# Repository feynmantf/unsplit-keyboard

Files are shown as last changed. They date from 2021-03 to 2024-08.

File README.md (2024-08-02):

# this project has been archived and abandoned in pursuit of hall-effect
# ~~WIP!! (firmware and schematic work but i havent gotten around to the new pcb layout) - I will get back to working on it when the semester ends/when I have the time~~
## all files in [early revisions/final but with microcontrollers](/early%20revisions/final%20but%20with%20microcontrollers) still work and can be manufactured (see [BOM](/early%20revisions/final%20but%20with%20microcontrollers/bom%20and%20cpl%20files) and [Gerber](/early%20revisions/final%20but%20with%20microcontrollers/gerber%20and%20drill%20files) folders), i just dont like the layout lol
## i plan on coming back to this project sometime before the end of 2024, but i cant promise it will look the same

# kaluza kb
kaluza kb pcb, layout, and case files (plus other useful stuff like firmware/images)
(documentation in progress)

## design logic
i wanted a keyboard that was both 65% and had extra function keys. i also wanted an oled panel and rotary encoder. and, as an added bonus, i love seeing through hole components on a keyboard. therefore, all of these features have been included

## sample images (they exist for the old revisions if you want to dig through the file tree)

### case images/renders:

### pcb images/renders:
#### pcb front (old version):
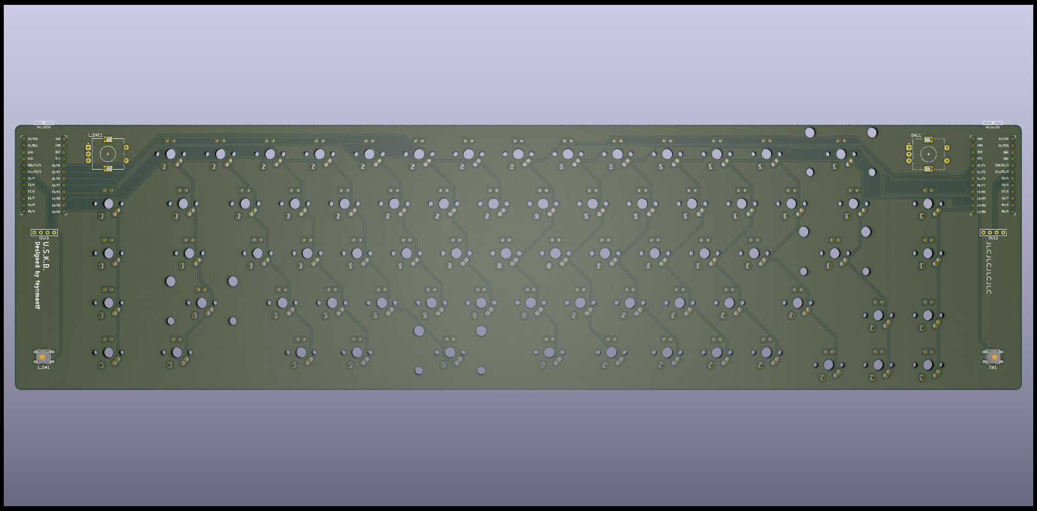
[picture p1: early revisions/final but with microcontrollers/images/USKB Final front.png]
pcb front

#### pcb back (old version):
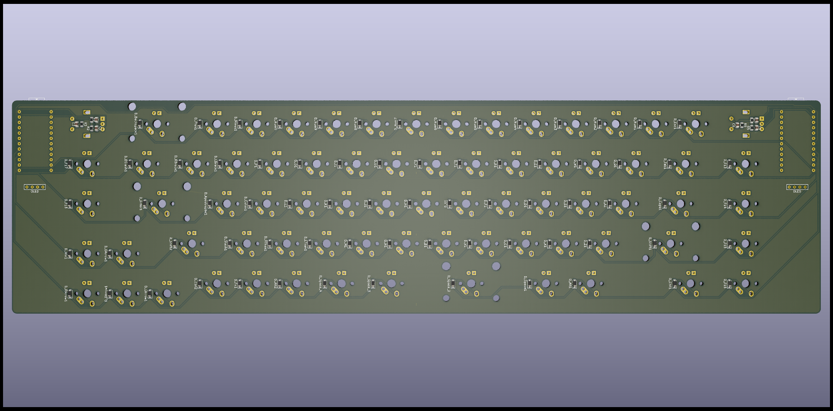
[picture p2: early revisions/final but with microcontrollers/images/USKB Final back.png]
pcb back

### schematic (new version):
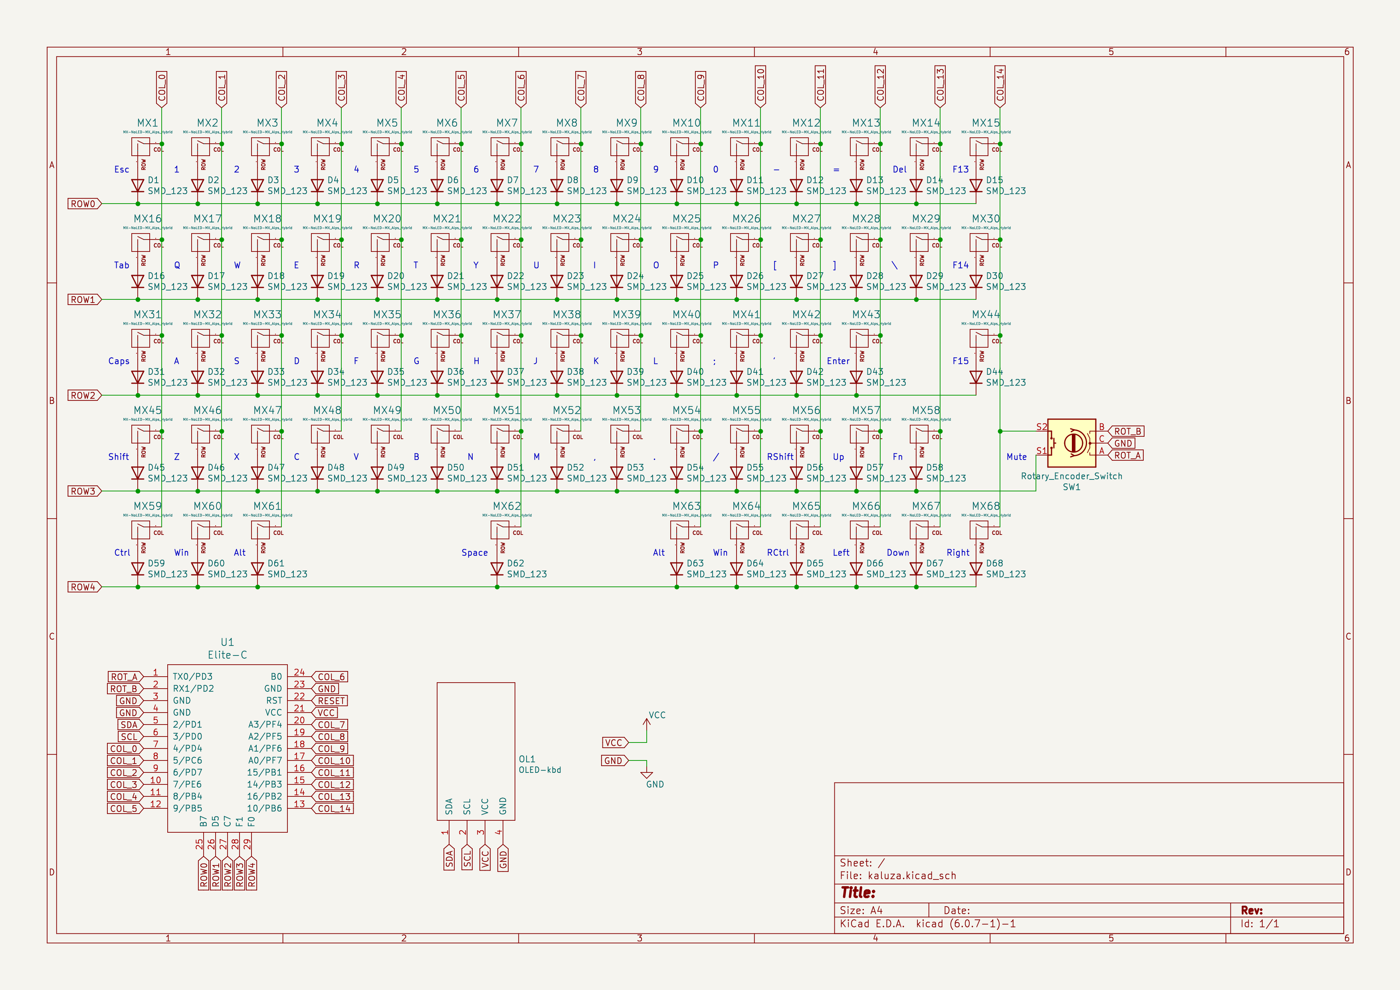
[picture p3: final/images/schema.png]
schematic


### handwired circuit test images:
handwired front
handwired back
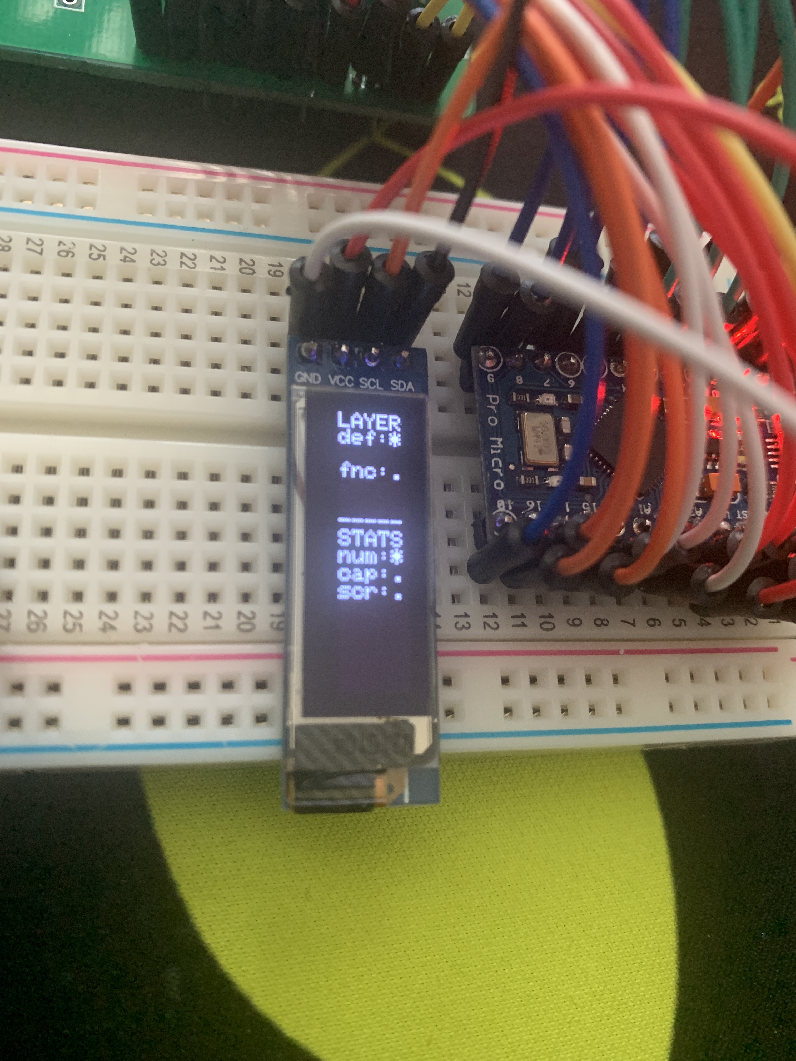
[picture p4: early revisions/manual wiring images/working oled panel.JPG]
oled panel test


## parts needed to build the board (not included in these files)
### parts you must source
- keyswitches (x80)
- keycaps (base kit and spacebar)
- pcb stabilizers (2u x4 and 6.25u x1)
- rotary knob (x1)
- rotary encoder (ec11 with switch) (x1)
- oled (0.91 inch, SSD1306) (x1)
- switch diodes (x80)
- elite-c v4 (x1)

### parts to get manufactured
- pcb
- plate (carbon fiber or sheet metal) (2mm)
- case (3d printed)
- leaf springs (carbon fiber) (1mm)

## basic instructions
- buy all the parts listed above
- get the pcb printed (from jlcpcb or some other service)
- get the plate, case, and leaf springs printed
- flash firmware and test the board to make sure everything works
- screw stabilizers into pcb
- align and place plate on top of pcb
- clip switches into place and slot them into the pcb
- solder switches to the pcb (locations marked on pcb)
- solder rotary encoder onto pcb (locations marked on pcb)
- solder oled panel onto pcb (locations marked on pcb)
- test everything again
- screw leaf springs into pcb (locations marked on pcb)
- put assembled pcb and plate in the case, and screw the case together
- you should be done now !!

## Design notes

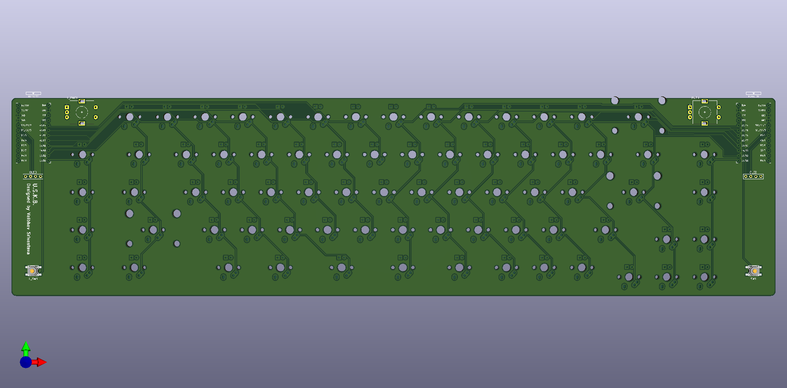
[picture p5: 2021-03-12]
early revisions/not really final cuz its missing one wire which means i need to redo the schematic lolololol/images/USKB Final but wrong and needs to be redone sadge (front).png

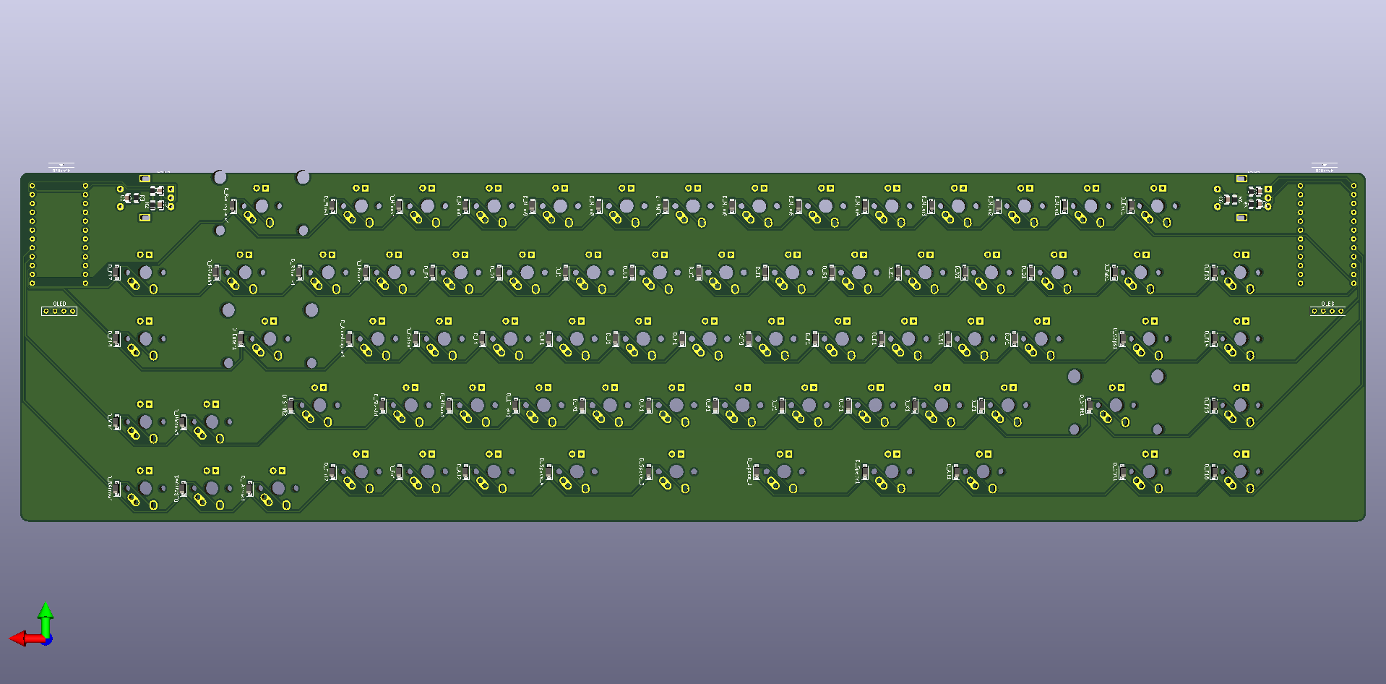
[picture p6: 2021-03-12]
early revisions/not really final cuz its missing one wire which means i need to redo the schematic lolololol/images/USKB Final but wrong and needs to be redone sadge (back).png

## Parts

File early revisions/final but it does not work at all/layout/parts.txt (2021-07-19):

keyswitches (x69)
keycaps (base kit and spacebar in 6.25u)
pcb or plate mount stabilizers (2u x3 and 1c 6.25u)
switch diodes (x70) (specs in BOM and surface mounted on pcb by manufacturer)
capacitors (x11) (specs in BOM and surface mounted on pcb by manufacturer)
resistors (x9) (specs in BOM and surface mounted on pcb by manufacturer)
reset switch (x1) (specs in BOM and surface mounted on pcb by manufacturer)
xtal crystal (x1) (specs in BOM and surface mounted on pcb by manufacturer)
usb-c port (x1) (specs in BOM and surface mounted on pcb by manufacturer)
rotary knob (x1)
rotary encoder (ec11 with switch) (x1)
oled (0.91 inch, SSD1306) (x1)

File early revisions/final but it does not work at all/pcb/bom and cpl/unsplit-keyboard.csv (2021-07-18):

Comment | Designator | Footprint | LCSC
22p | C1,C2 | Capacitor_SMD:C_0805_2012Metric | C1804
1u | C11 | Capacitor_SMD:C_0805_2012Metric | C28323
0.1u | C3,C4,C5,C6,C7,C9,C10 | Capacitor_SMD:C_0805_2012Metric | C49678
4.7u | C8 | Capacitor_SMD:C_0805_2012Metric | C1779
SOD-123 | D1,D2,D3,D4,D5,D6,D7,D8,D9,D10,D11,D12,D13,D14,D15,D16,D17,D18,D19,D20,D21,D22,D23,D24,D25,D26,D27,D28,D29,D30,D31,D32,D33,D34,D35,D36,D37,D38,D39,D40,D41,D42,D43,D44,D45,D46,D47,D48,D49,D50,D51,D52,D53,D54,D55,D56,D57,D58,D59,D60,D61,D62,D63,D64,D65,D66,D67,D68,D69,D70 | Diode_SMD:D_0805_2012Metric | C81598
10k | R1,R4,R5,R6,R7 | Resistor_SMD:R_0805_2012Metric | C17414
22Ω | R2,R3 | Resistor_SMD:R_0805_2012Metric | C17561
5.1kΩ | R8,R9 | Resistor_SMD:R_0805_2012Metric | C27834
TS-1187A-B-A-B | SW1 | Keyboard Master List:SKQG-1155865 | C318884
ATmega32U4-AU | U1 | Keebio Parts:ATMEGA32U4-AU | C44854
HRO-TYPE-C-31-M-12 | USB1 | Keebio Parts:USB-C-12-Pin-MidMount | C165948
XTAL_3225 | X1 | Keebio Parts:Crystal_SMD_3225-4pin_3.2x2.5mm | C13738

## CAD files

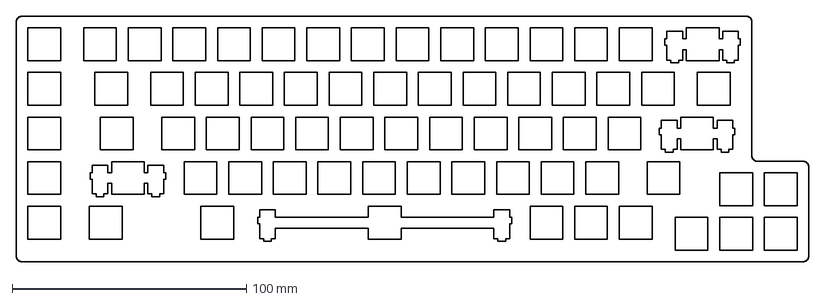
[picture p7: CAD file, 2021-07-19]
early revisions/final but it does not work at all/case/plate.dxf
338.1 x 104.8 mm

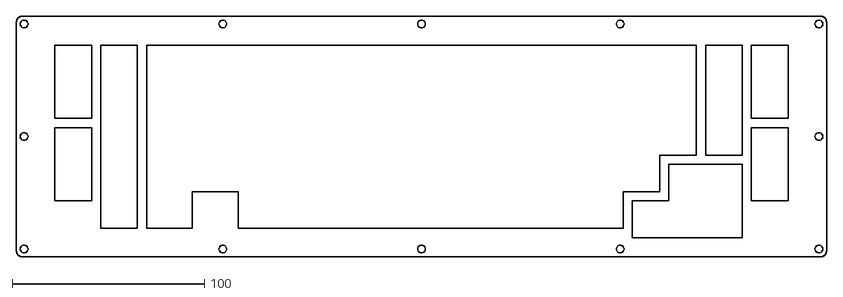
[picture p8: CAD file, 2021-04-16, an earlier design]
early revisions/old plate files bad/top.dxf
421.0 x 125.0

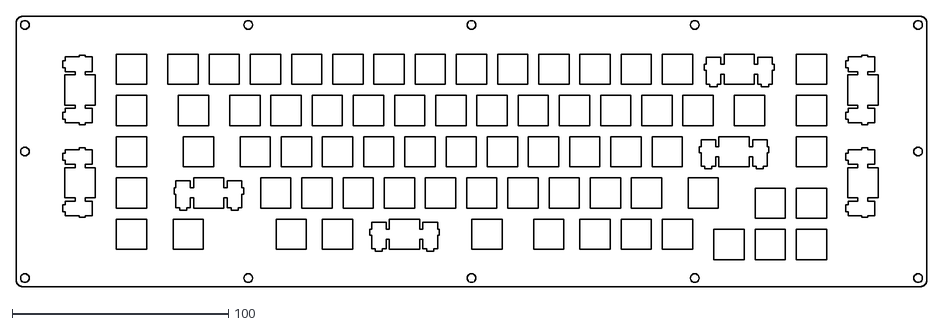
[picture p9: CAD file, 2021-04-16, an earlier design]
early revisions/old plate files bad/switch.dxf
421.0 x 125.0

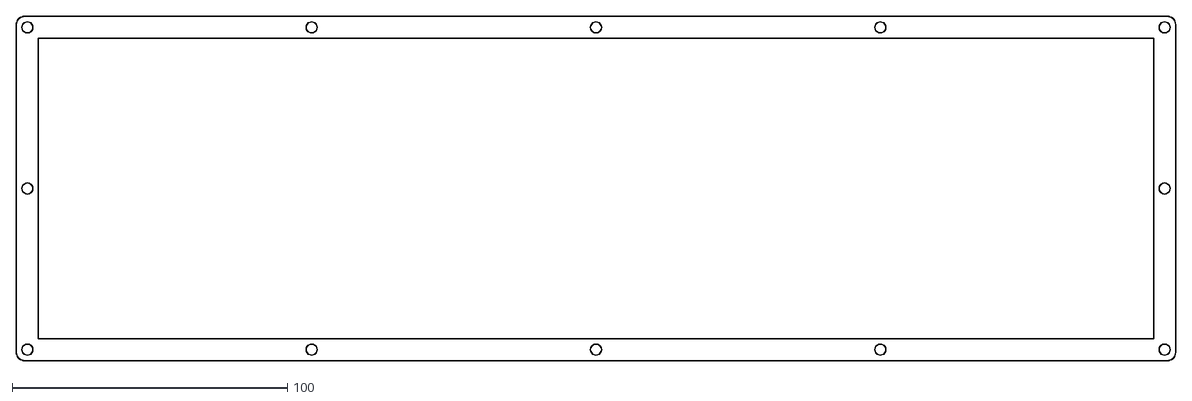
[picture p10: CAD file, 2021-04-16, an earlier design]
early revisions/old plate files bad/closed.dxf
421.0 x 125.0

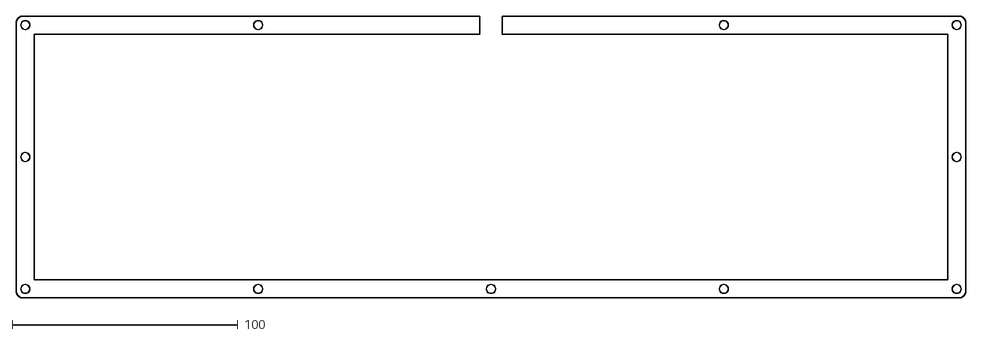
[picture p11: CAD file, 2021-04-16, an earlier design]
early revisions/old plate files bad/open.dxf
421.0 x 125.0

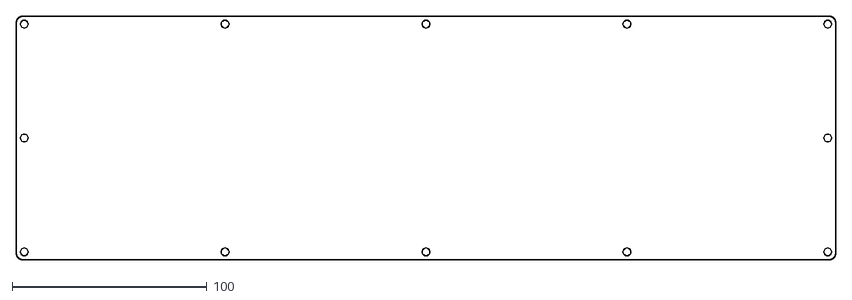
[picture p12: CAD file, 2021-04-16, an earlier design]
early revisions/old plate files bad/bottom.dxf
421.0 x 125.0

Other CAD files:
early revisions/final but with microcontrollers/plate and case files/top.dwg
early revisions/final but with microcontrollers/plate and case files/switch.dwg
early revisions/final but with microcontrollers/plate and case files/USKB Final-F_SilkS.dwg
early revisions/final but with microcontrollers/plate and case files/closed.dwg
early revisions/final but with microcontrollers/plate and case files/open.dwg
early revisions/final but with microcontrollers/plate and case files/bottom.dwg
early revisions/not really final cuz its missing one wire which means i need to redo the schematic lolololol/plate and case/switch plate maybe old why not.dwg
early revisions/not really final cuz its missing one wire which means i need to redo the schematic lolololol/plate and case/switch plate old.dwg
early revisions/old plate files bad/top but thin holes.dwg
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

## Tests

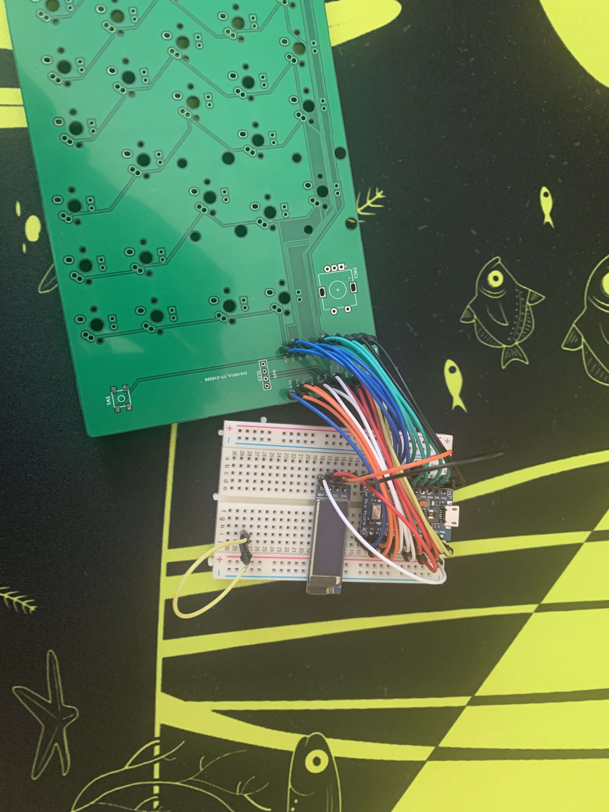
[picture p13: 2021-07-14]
early revisions/manual wiring images/testing the oled panel.jpg

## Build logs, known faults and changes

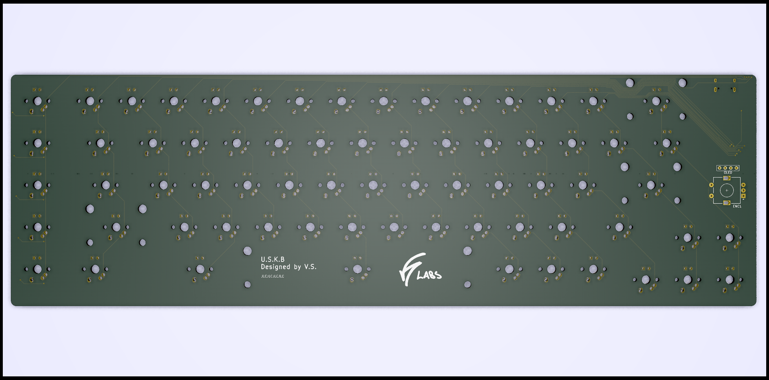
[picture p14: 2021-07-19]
early revisions/final but it does not work at all/images/uskb front.png

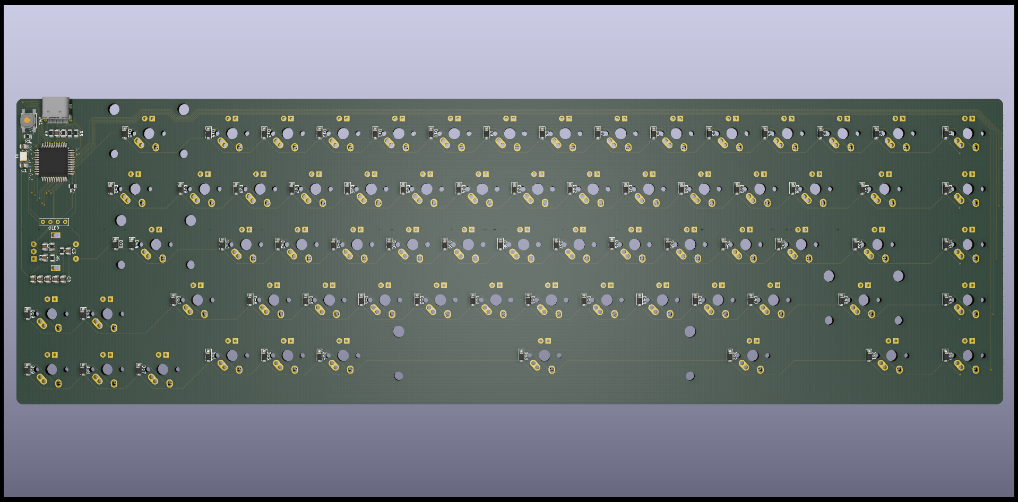
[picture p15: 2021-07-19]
early revisions/final but it does not work at all/images/uskb back.png

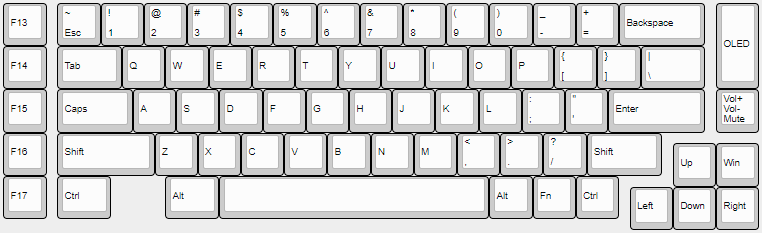
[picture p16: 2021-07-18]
early revisions/final but it does not work at all/images/layout.png

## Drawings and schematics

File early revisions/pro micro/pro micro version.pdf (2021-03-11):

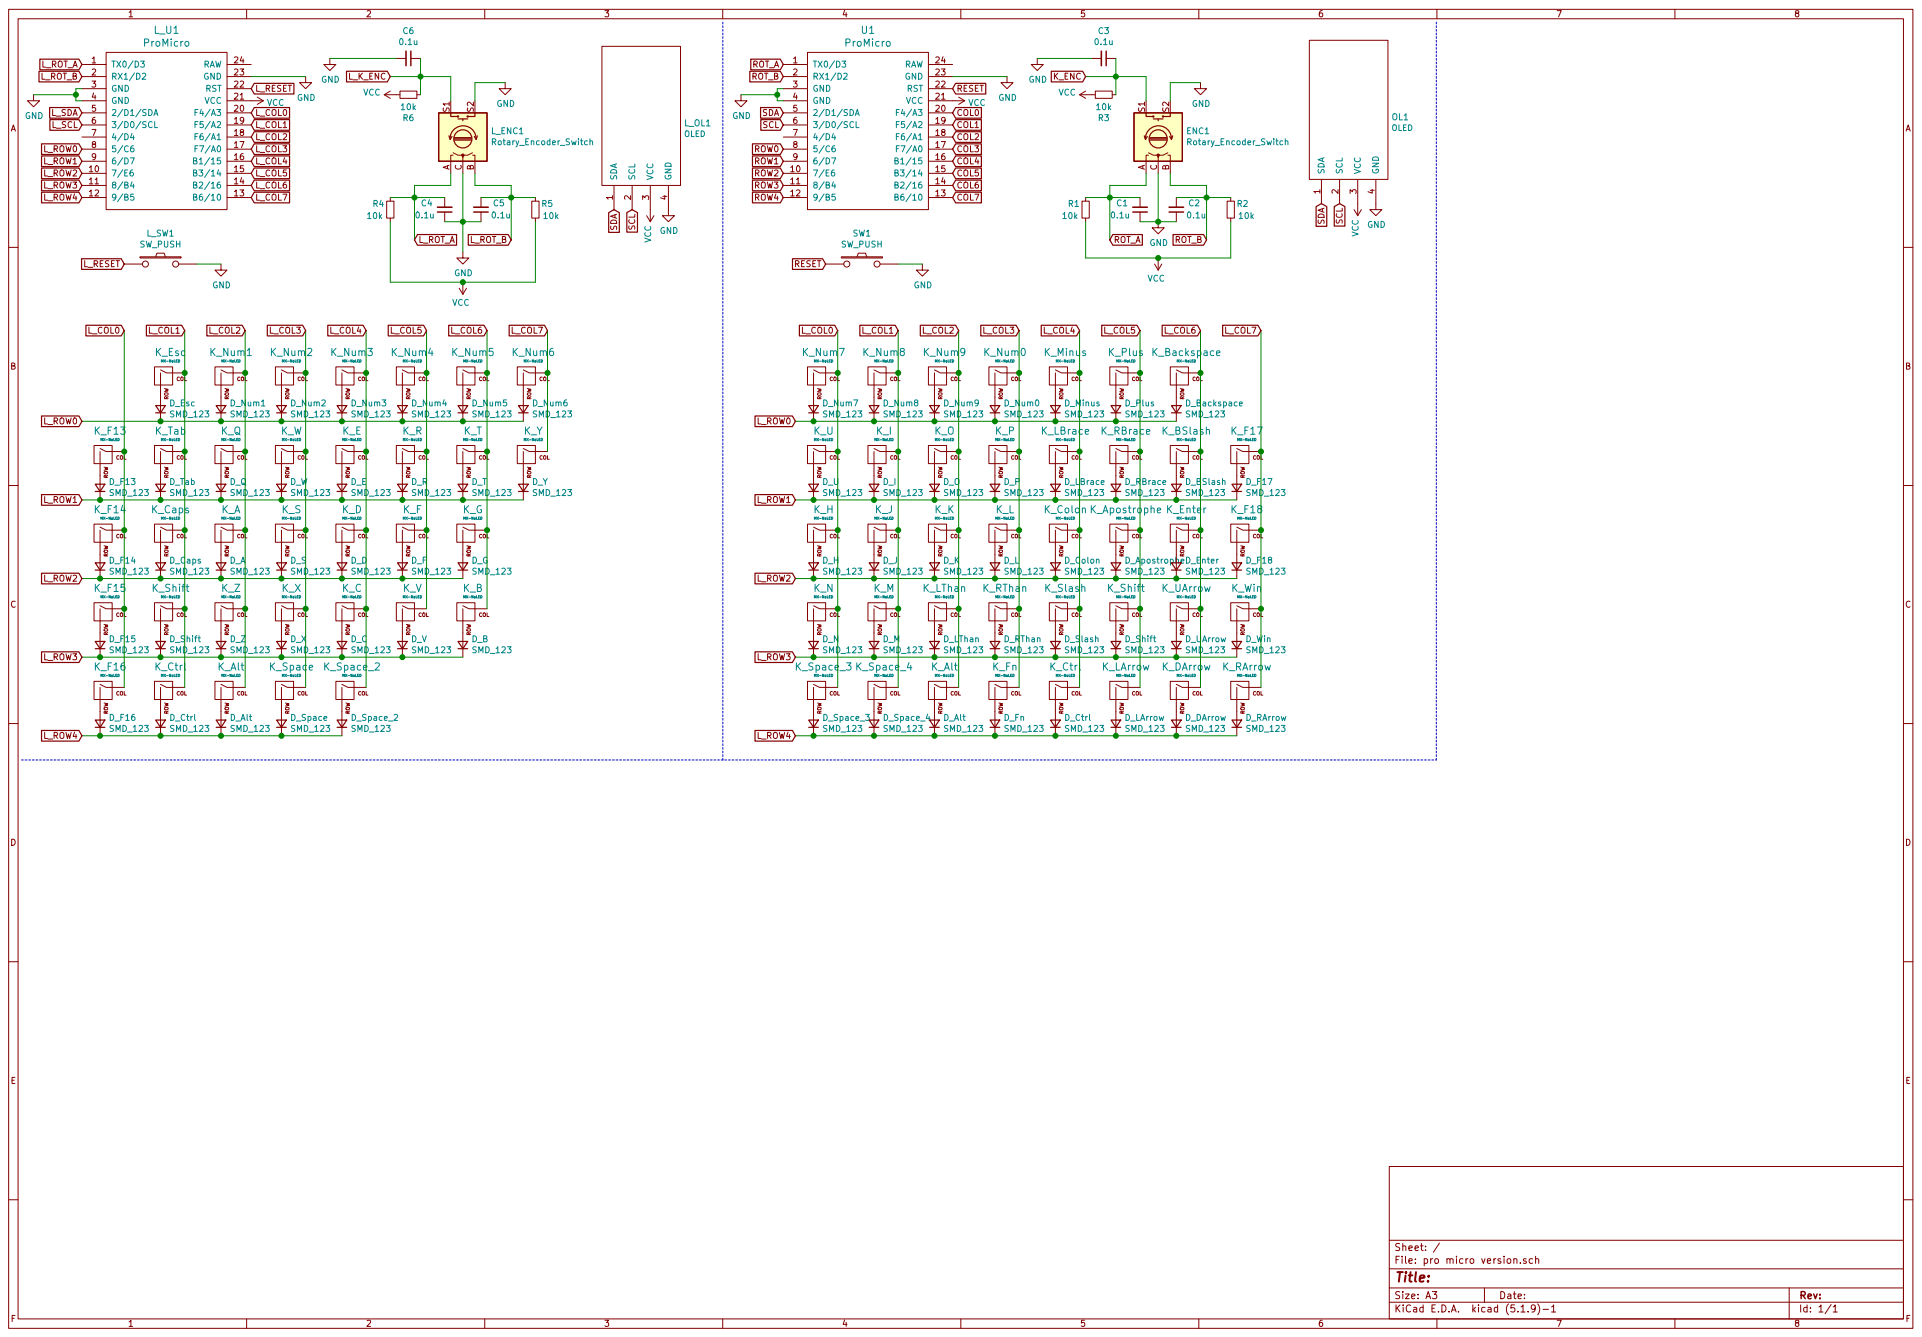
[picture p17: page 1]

0.1u VCC GND GND VCC SDA

MX-NoLED COL ROW K_Z

MX-NoLED COL ROW K_F13

SMD_123
COL ROW K_M MX-NoLED D_M
MX-NoLED D_N

Id: 1/1 Title: File: pro micro version.sch Sheet: /

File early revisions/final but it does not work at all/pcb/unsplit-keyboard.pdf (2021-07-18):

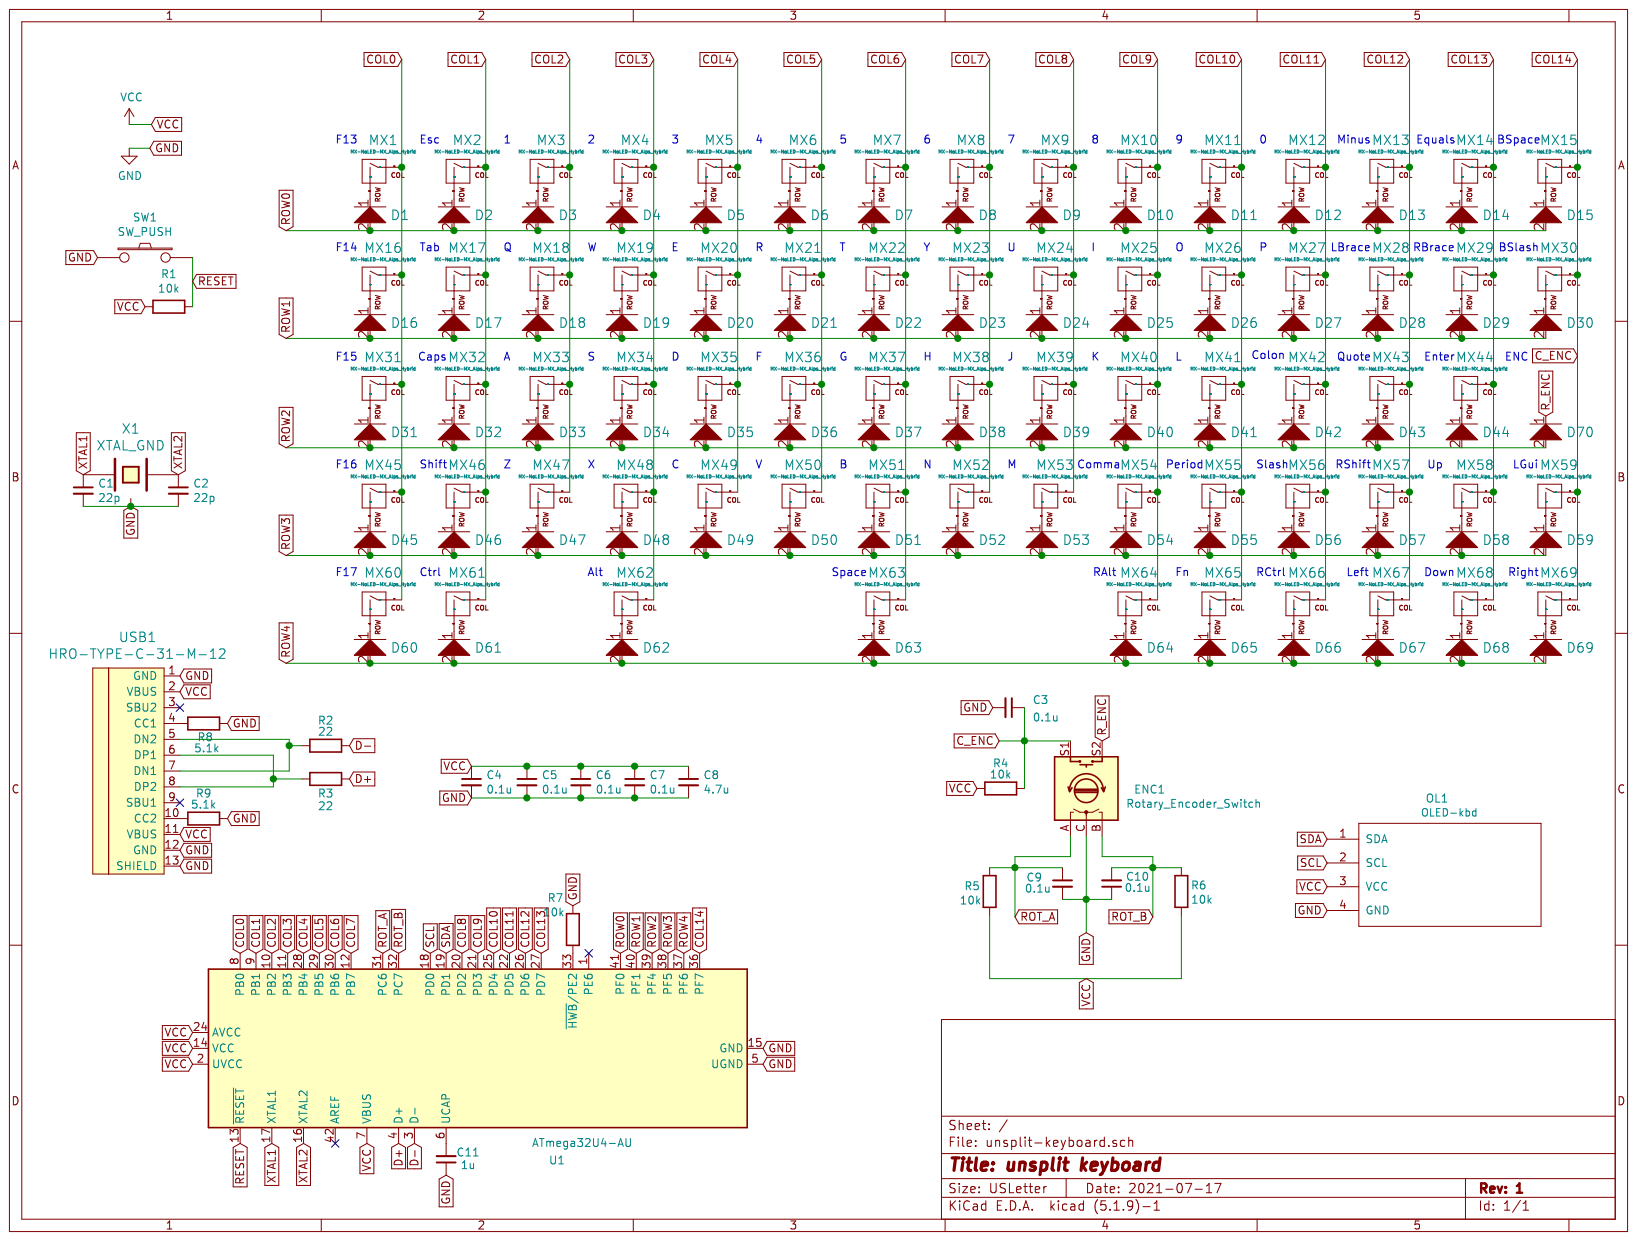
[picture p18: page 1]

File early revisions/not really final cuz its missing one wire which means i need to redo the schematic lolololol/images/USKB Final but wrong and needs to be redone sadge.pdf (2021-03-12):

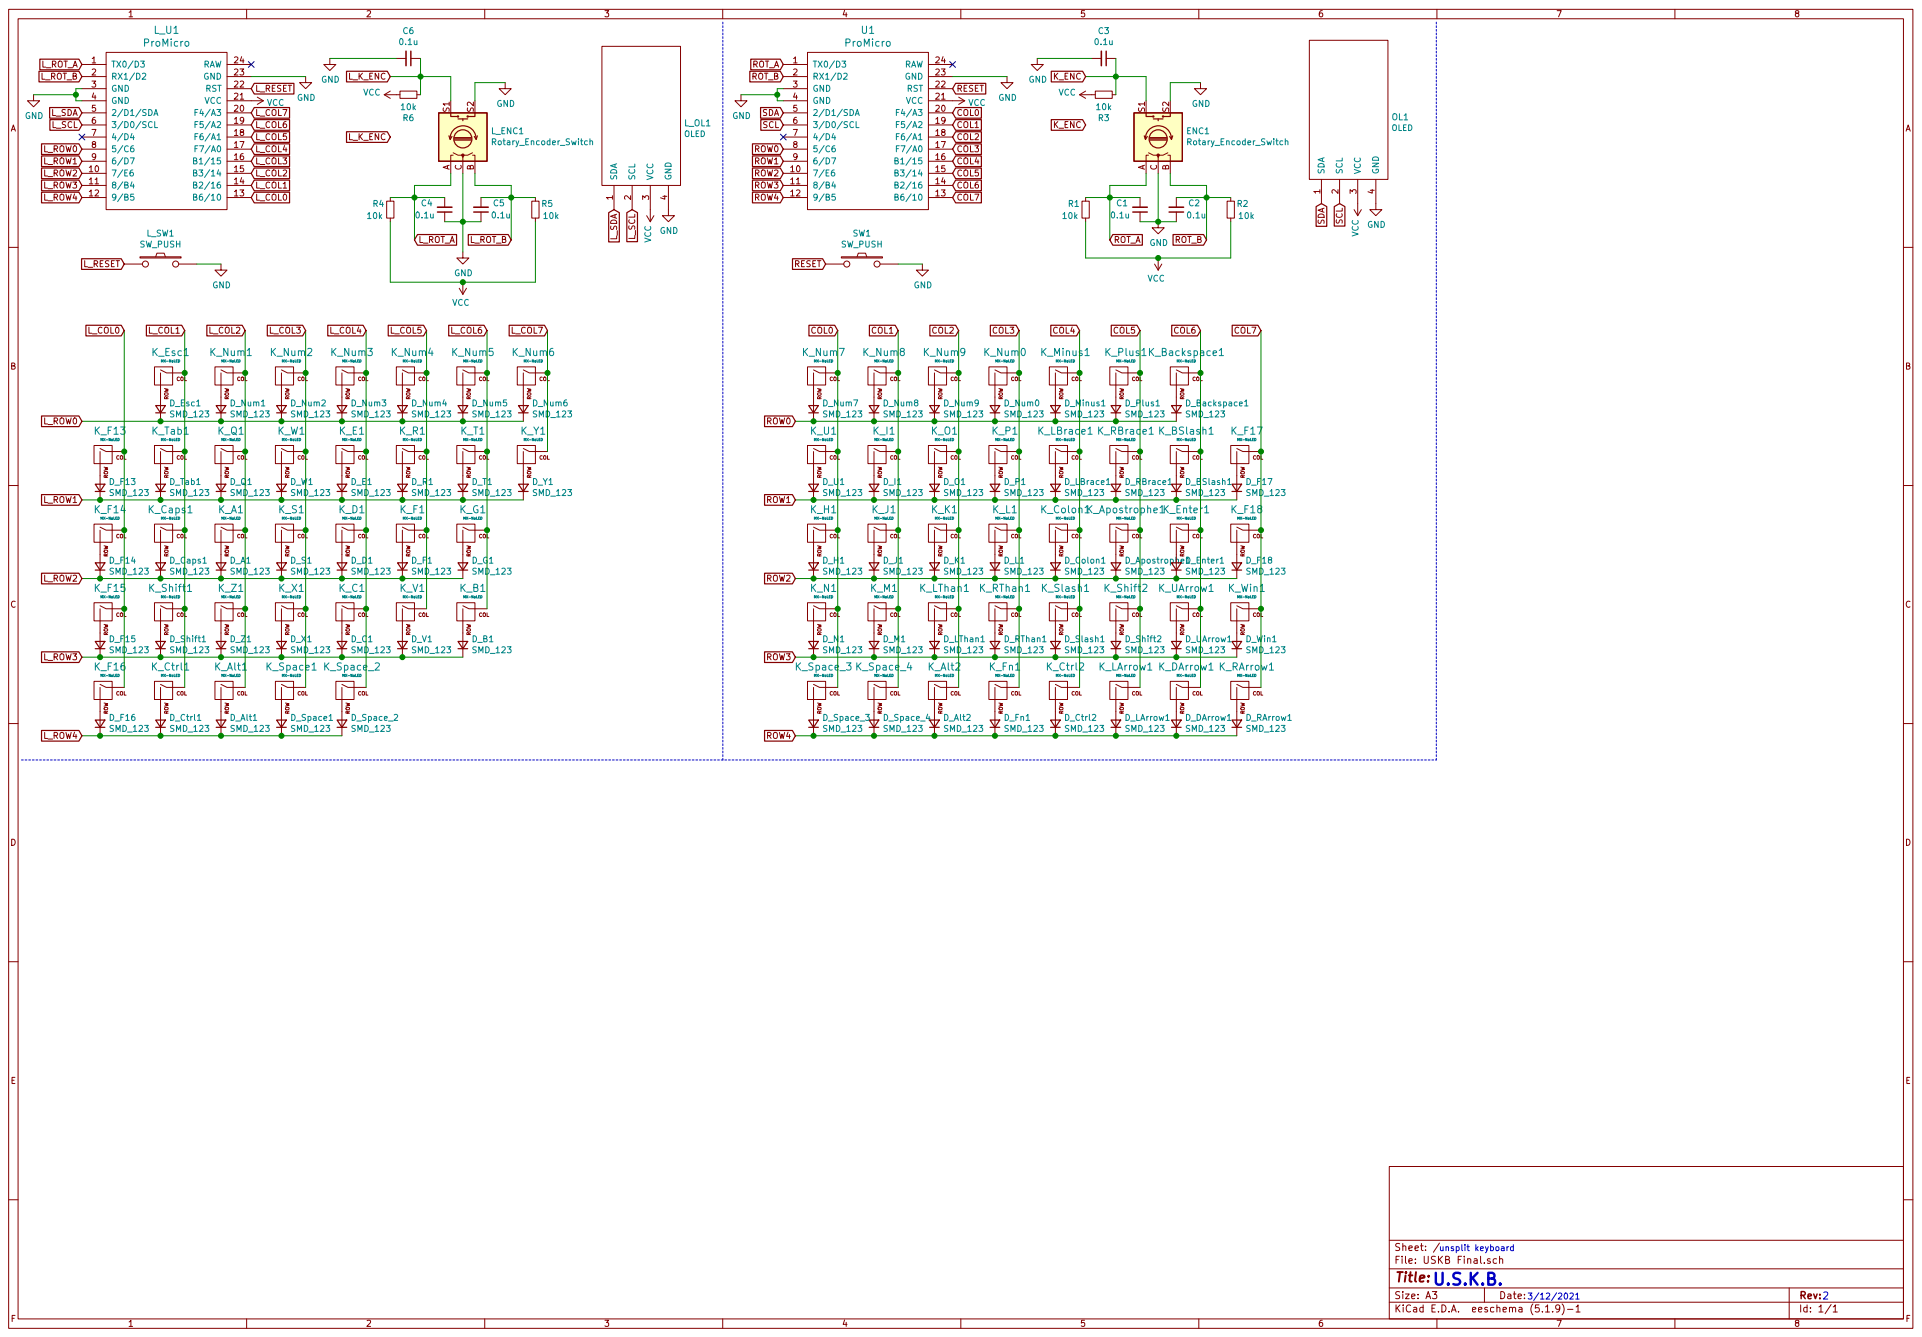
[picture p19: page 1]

MX-NoLED COL ROW K_A1

MX-NoLED COL ROW K_Space_3

MX-NoLED COL ROW K_F13

Id: 1/1 Title: File: USKB Final.sch Sheet: /

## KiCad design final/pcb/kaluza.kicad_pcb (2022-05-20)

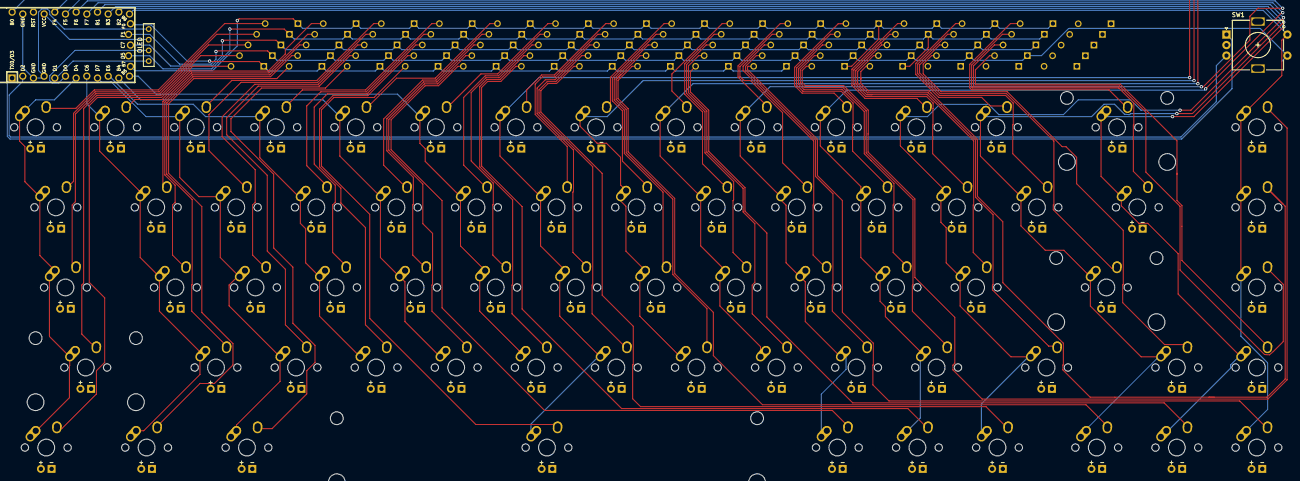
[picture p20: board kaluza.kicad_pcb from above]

Board: 2 copper layers, 146 parts (0 on the bottom side), 94 nets.

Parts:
D1, D2, D3, D4, D5, D6, D7, D8, D9, D10, D11, D12, D13, D14, D15, D16, D17, D18, D19, D20, D21, D22, D23, D24, D25, D26, D27, D28, D29, D30, D31, D32, D33, D34, D35, D36, D37, D38, D39, D40, D41, D42, D43, D44, D45, D46, D47, D48, D49, D50, D51, D52, D53, D54, D55, D56, D57, D58, D59, D60, D61, D62, D63, D64, D65, D66, D67, D68: SMD_123; Diode-Hybrid-Back
D_Spare: SMD_123; Diode-Hybrid-Back
D_Spare#2, D_Spare#3, D_Spare#4, D_Spare#5, D_Spare#6, D_Spare#7: SMD_123; Diode-Hybrid-Back
MX1, MX2, MX3, MX4, MX5, MX6, MX7, MX8, MX9, MX10, MX11, MX12, MX13, MX15, MX17, MX18, MX19, MX20, MX21, MX22, MX23, MX24, MX25, MX26, MX27, MX28, MX30, MX32, MX33, MX34, MX35, MX36, MX37, MX38, MX39, MX40, MX41, MX42, MX44, MX46, MX47, MX48, MX49, MX50, MX51, MX52, MX53, MX54, MX55, MX57, MX58, MX63, MX64, MX65, MX66, MX67, MX68: MX-NoLED-MX_Alps_Hybrid; MX-1U
MX14: MX-NoLED-MX_Alps_Hybrid; MX-2U
MX16, MX29: MX-NoLED-MX_Alps_Hybrid; MX-1.5U
MX31, MX56: MX-NoLED-MX_Alps_Hybrid; MX-1.75U
MX43, MX45: MX-NoLED-MX_Alps_Hybrid; MX-2.25U
MX59, MX60, MX61: MX-NoLED-MX_Alps_Hybrid; MX-1.25U
MX62: MX-NoLED-MX_Alps_Hybrid; MX-6.25U
OL1: OLED-kbd; OLED
SW1: Rotary_Encoder_Switch; RotaryEncoder_Alps_EC11E-Switch_Vertical_H20mm
U1: Elite-C; Elite-C-ZigZag

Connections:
COL_0: MX1.1, MX16.1, MX31.1, MX45.1, MX59.1, U1.7
COL_1: MX2.1, MX17.1, MX32.1, MX46.1, MX60.1, U1.8
COL_2: MX3.1, MX18.1, MX33.1, MX47.1, MX61.1, U1.9
COL_3: MX4.1, MX19.1, MX34.1, MX48.1, U1.10
COL_4: MX5.1, MX20.1, MX35.1, MX49.1, U1.11
COL_5: MX6.1, MX21.1, MX36.1, MX50.1, U1.12
COL_6: MX7.1, MX22.1, MX37.1, MX51.1, MX62.1, U1.24
COL_7: MX8.1, MX23.1, MX38.1, MX52.1, U1.20
COL_8: MX9.1, MX24.1, MX39.1, MX53.1, U1.19
COL_9: MX10.1, MX25.1, MX40.1, MX54.1, MX63.1, U1.18
COL_10: MX11.1, MX26.1, MX41.1, MX55.1, MX64.1, U1.17
COL_11: MX12.1, MX27.1, MX42.1, MX56.1, MX65.1, U1.16
COL_12: MX13.1, MX28.1, MX43.1, MX57.1, MX66.1, U1.15
COL_13: MX14.1, MX29.1, MX58.1, MX67.1, U1.14
COL_14: MX15.1, MX30.1, MX44.1, MX68.1, SW1.S2, U1.13
GND: OL1.4, SW1.C, U1.3, U1.4, U1.23
unnamed: D1.2, MX1.2
unnamed: D2.2, MX2.2
unnamed: D3.2, MX3.2
unnamed: D4.2, MX4.2
unnamed: D5.2, MX5.2
unnamed: D6.2, MX6.2
unnamed: D7.2, MX7.2
unnamed: D8.2, MX8.2
unnamed: D9.2, MX9.2
unnamed: D10.2, MX10.2
unnamed: D11.2, MX11.2
unnamed: D12.2, MX12.2
unnamed: D13.2, MX13.2
unnamed: D14.2, MX14.2
unnamed: D15.2, MX15.2
unnamed: D16.2, MX16.2
unnamed: D17.2, MX17.2
unnamed: D18.2, MX18.2
unnamed: D19.2, MX19.2
unnamed: D20.2, MX20.2
unnamed: D21.2, MX21.2
unnamed: D22.2, MX22.2
unnamed: D23.2, MX23.2
unnamed: D24.2, MX24.2
unnamed: D25.2, MX25.2
unnamed: D26.2, MX26.2
unnamed: D27.2, MX27.2
unnamed: D28.2, MX28.2
unnamed: D29.2, MX29.2
unnamed: D30.2, MX30.2
unnamed: D31.2, MX31.2
unnamed: D32.2, MX32.2
unnamed: D33.2, MX33.2
unnamed: D34.2, MX34.2
unnamed: D35.2, MX35.2
unnamed: D36.2, MX36.2
unnamed: D37.2, MX37.2
unnamed: D38.2, MX38.2
unnamed: D39.2, MX39.2
unnamed: D40.2, MX40.2
unnamed: D41.2, MX41.2
unnamed: D42.2, MX42.2
unnamed: D43.2, MX43.2
unnamed: D44.2, MX44.2
unnamed: D45.2, MX45.2
unnamed: D46.2, MX46.2
unnamed: D47.2, MX47.2
unnamed: D48.2, MX48.2
unnamed: D49.2, MX49.2
unnamed: D50.2, MX50.2
unnamed: D51.2, MX51.2
unnamed: D52.2, MX52.2
unnamed: D53.2, MX53.2
unnamed: D54.2, MX54.2
unnamed: D55.2, MX55.2
unnamed: D56.2, MX56.2
unnamed: D57.2, MX57.2
unnamed: D58.2, MX58.2
unnamed: D59.2, MX59.2
unnamed: D60.2, MX60.2
unnamed: D61.2, MX61.2
unnamed: D62.2, MX62.2
unnamed: D63.2, MX63.2
unnamed: D64.2, MX64.2
unnamed: D65.2, MX65.2
unnamed: D66.2, MX66.2
unnamed: D67.2, MX67.2
unnamed: D68.2, MX68.2
ROT_A: SW1.A, U1.1
ROT_B: SW1.B, U1.2
ROW0: D1.1, D2.1, D3.1, D4.1, D5.1, D6.1, D7.1, D8.1, D9.1, D10.1, D11.1, D12.1, D13.1, D14.1, D15.1, U1.25
ROW1: D16.1, D17.1, D18.1, D19.1, D20.1, D21.1, D22.1, D23.1, D24.1, D25.1, D26.1, D27.1, D28.1, D29.1, D30.1, U1.26
ROW2: D31.1, D32.1, D33.1, D34.1, D35.1, D36.1, D37.1, D38.1, D39.1, D40.1, D41.1, D42.1, D43.1, D44.1, U1.27
ROW3: D45.1, D46.1, D47.1, D48.1, D49.1, D50.1, D51.1, D52.1, D53.1, D54.1, D55.1, D56.1, D57.1, D58.1, SW1.S1, U1.28
ROW4: D59.1, D60.1, D61.1, D62.1, D63.1, D64.1, D65.1, D66.1, D67.1, D68.1, U1.29
SCL: OL1.2, U1.6
SDA: OL1.1, U1.5
VCC: OL1.3, U1.21

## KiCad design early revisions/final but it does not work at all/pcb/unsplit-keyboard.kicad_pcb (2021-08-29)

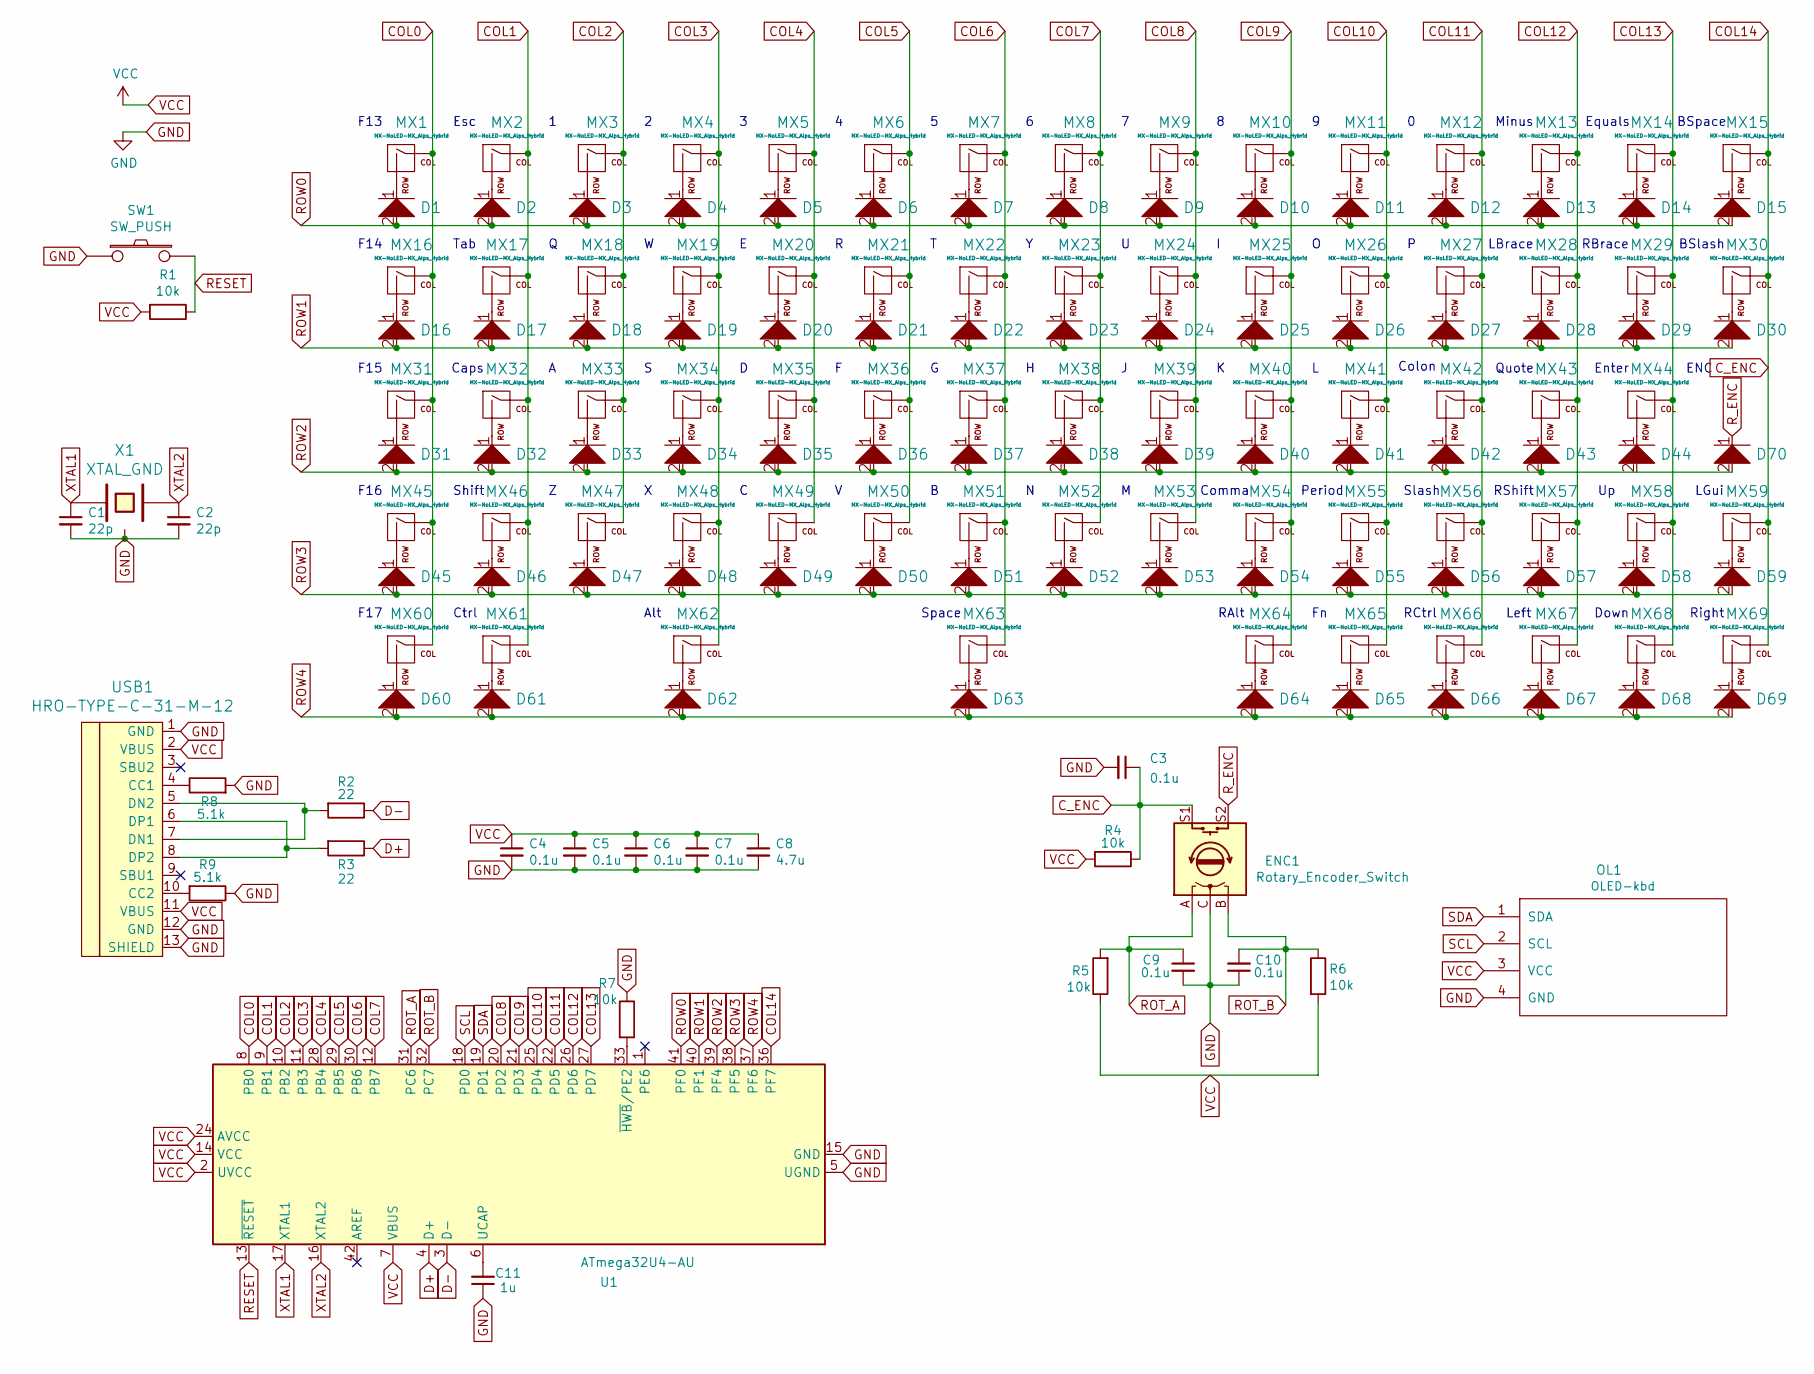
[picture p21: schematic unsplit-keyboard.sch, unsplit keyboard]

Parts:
C1, C2: 22p; C_0805_2012Metric
C3, C4, C5, C6, C7, C9, C10: 0.1u; C_0805_2012Metric
C8: 4.7u; C_0805_2012Metric
C11: 1u; C_0805_2012Metric
D1, D2, D3, D4, D5, D6, D7, D8, D9, D10, D11, D12, D13, D14, D15, D16, D17, D18, D19, D20, D21, D22, D23, D24, D25, D26, D27, D28, D29, D30, D31, D32, D33, D34, D35, D36, D37, D38, D39, D40, D41, D42, D43, D44, D45, D46, D47, D48, D49, D50, D51, D52, D53, D54, D55, D56, D57, D58, D59, D60, D61, D62, D63, D64, D65, D66, D67, D68, D69, D70: D; D_0805_2012Metric
ENC1: Rotary_Encoder_Switch; RotaryEncoder_Alps_EC11E-Switch_Vertical_H20mm
MX1, MX2, MX3, MX4, MX5, MX6, MX7, MX8, MX9, MX10, MX11, MX12, MX13, MX14, MX16, MX18, MX19, MX20, MX21, MX22, MX23, MX24, MX25, MX26, MX27, MX28, MX29, MX31, MX33, MX34, MX35, MX36, MX37, MX38, MX39, MX40, MX41, MX42, MX43, MX45, MX47, MX48, MX49, MX50, MX51, MX52, MX53, MX54, MX55, MX56, MX58, MX59, MX60, MX64, MX65, MX66, MX67, MX68, MX69: MX-NoLED-MX_Alps_Hybrid; MX-1U
MX15: MX-NoLED-MX_Alps_Hybrid; MX-2U
MX17, MX30: MX-NoLED-MX_Alps_Hybrid; MX-1.5U
MX32, MX57: MX-NoLED-MX_Alps_Hybrid; MX-1.75U
MX44, MX46: MX-NoLED-MX_Alps_Hybrid; MX-2.25U
MX61, MX62: MX-NoLED-MX_Alps_Hybrid; MX-1.25U
MX63: MX-NoLED-MX_Alps_Hybrid; MX-6.25U
OL1: OLED-kbd; OLED
R1, R4, R5, R6, R7: 10k; R_0805_2012Metric
R2, R3: 22; R_0805_2012Metric
R8, R9: 5.1k; R_0805_2012Metric
SW1: SW_PUSH; SKQG-1155865
U1: ATmega32U4-AU; ATMEGA32U4-AU
USB1: HRO-TYPE-C-31-M-12; HRO-TYPE-C-31-M-12-Assembly
X1: XTAL_GND; Crystal_SMD_3225-4pin_3.2x2.5mm

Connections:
COL0: MX1.1 (COL), MX16.1 (COL), MX31.1 (COL), MX45.1 (COL), MX60.1 (COL), U1.8 (PB0)
COL1: MX2.1 (COL), MX17.1 (COL), MX32.1 (COL), MX46.1 (COL), MX61.1 (COL), U1.9 (PB1)
COL2: MX3.1 (COL), MX18.1 (COL), MX33.1 (COL), MX47.1 (COL), U1.10 (PB2)
COL3: MX4.1 (COL), MX19.1 (COL), MX34.1 (COL), MX48.1 (COL), MX62.1 (COL), U1.11 (PB3)
COL4: MX5.1 (COL), MX20.1 (COL), MX35.1 (COL), MX49.1 (COL), U1.28 (PB4)
COL5: MX6.1 (COL), MX21.1 (COL), MX36.1 (COL), MX50.1 (COL), U1.29 (PB5)
COL6: MX7.1 (COL), MX22.1 (COL), MX37.1 (COL), MX51.1 (COL), MX63.1 (COL), U1.30 (PB6)
COL7: MX8.1 (COL), MX23.1 (COL), MX38.1 (COL), MX52.1 (COL), U1.12 (PB7)
COL8: MX9.1 (COL), MX24.1 (COL), MX39.1 (COL), MX53.1 (COL), U1.20 (PD2)
COL9: MX10.1 (COL), MX25.1 (COL), MX40.1 (COL), MX54.1 (COL), MX64.1 (COL), U1.21 (PD3)
COL10: MX11.1 (COL), MX26.1 (COL), MX41.1 (COL), MX55.1 (COL), MX65.1 (COL), U1.25 (PD4)
COL11: MX12.1 (COL), MX27.1 (COL), MX42.1 (COL), MX56.1 (COL), MX66.1 (COL), U1.22 (PD5)
COL12: MX13.1 (COL), MX28.1 (COL), MX43.1 (COL), MX57.1 (COL), MX67.1 (COL), U1.26 (PD6)
COL13: MX14.1 (COL), MX29.1 (COL), MX44.1 (COL), MX58.1 (COL), MX68.1 (COL), U1.27 (PD7)
COL14: C3.1, ENC1.S1, MX15.1 (COL), MX30.1 (COL), MX59.1 (COL), MX69.1 (COL), R4.1, U1.36 (PF7)
D+: R3.1, U1.4 (D+)
D-: R2.1, U1.3 (D-)
GND: C1.2, C2.2, C3.2, C4.2, C5.2, C6.2, C7.2, C8.2, C9.2, C10.1, C11.1, ENC1.C, OL1.4 (GND), R7.1, R8.2, R9.1, SW1.1, U1.5 (UGND), U1.15 (GND), U1.23 (GND), U1.35 (GND), U1.43 (GND), USB1.1 (GND), USB1.12 (GND), USB1.13 (SHIELD), X1.3
unnamed: C11.2, U1.6 (UCAP)
unnamed: D1.1, MX1.2 (ROW)
unnamed: D2.1, MX2.2 (ROW)
unnamed: D3.1, MX3.2 (ROW)
unnamed: D4.1, MX4.2 (ROW)
unnamed: D5.1, MX5.2 (ROW)
unnamed: D6.1, MX6.2 (ROW)
unnamed: D7.1, MX7.2 (ROW)
unnamed: D8.1, MX8.2 (ROW)
unnamed: D9.1, MX9.2 (ROW)
unnamed: D10.1, MX10.2 (ROW)
unnamed: D11.1, MX11.2 (ROW)
unnamed: D12.1, MX12.2 (ROW)
unnamed: D13.1, MX13.2 (ROW)
unnamed: D14.1, MX14.2 (ROW)
unnamed: D15.1, MX15.2 (ROW)
unnamed: D16.1, MX16.2 (ROW)
unnamed: D17.1, MX17.2 (ROW)
unnamed: D18.1, MX18.2 (ROW)
unnamed: D19.1, MX19.2 (ROW)
unnamed: D20.1, MX20.2 (ROW)
unnamed: D21.1, MX21.2 (ROW)
unnamed: D22.1, MX22.2 (ROW)
unnamed: D23.1, MX23.2 (ROW)
unnamed: D24.1, MX24.2 (ROW)
unnamed: D25.1, MX25.2 (ROW)
unnamed: D26.1, MX26.2 (ROW)
unnamed: D27.1, MX27.2 (ROW)
unnamed: D28.1, MX28.2 (ROW)
unnamed: D29.1, MX29.2 (ROW)
unnamed: D30.1, MX30.2 (ROW)
unnamed: D31.1, MX31.2 (ROW)
unnamed: D32.1, MX32.2 (ROW)
unnamed: D33.1, MX33.2 (ROW)
unnamed: D34.1, MX34.2 (ROW)
unnamed: D35.1, MX35.2 (ROW)
unnamed: D36.1, MX36.2 (ROW)
unnamed: D37.1, MX37.2 (ROW)
unnamed: D38.1, MX38.2 (ROW)
unnamed: D39.1, MX39.2 (ROW)
unnamed: D40.1, MX40.2 (ROW)
unnamed: D41.1, MX41.2 (ROW)
unnamed: D42.1, MX42.2 (ROW)
unnamed: D43.1, MX43.2 (ROW)
unnamed: D44.1, MX44.2 (ROW)
unnamed: D45.1, MX45.2 (ROW)
unnamed: D46.1, MX46.2 (ROW)
unnamed: D47.1, MX47.2 (ROW)
unnamed: D48.1, MX48.2 (ROW)
unnamed: D49.1, MX49.2 (ROW)
unnamed: D50.1, MX50.2 (ROW)
unnamed: D51.1, MX51.2 (ROW)
unnamed: D52.1, MX52.2 (ROW)
unnamed: D53.1, MX53.2 (ROW)
unnamed: D54.1, MX54.2 (ROW)
unnamed: D55.1, MX55.2 (ROW)
unnamed: D56.1, MX56.2 (ROW)
unnamed: D57.1, MX57.2 (ROW)
unnamed: D58.1, MX58.2 (ROW)
unnamed: D59.1, MX59.2 (ROW)
unnamed: D60.1, MX60.2 (ROW)
unnamed: D61.1, MX61.2 (ROW)
unnamed: D62.1, MX62.2 (ROW)
unnamed: D63.1, MX63.2 (ROW)
unnamed: D64.1, MX64.2 (ROW)
unnamed: D65.1, MX65.2 (ROW)
unnamed: D66.1, MX66.2 (ROW)
unnamed: D67.1, MX67.2 (ROW)
unnamed: D68.1, MX68.2 (ROW)
unnamed: D69.1, MX69.2 (ROW)
unnamed: R2.2, USB1.5 (DN2), USB1.7 (DN1)
unnamed: R3.2, USB1.6 (DP1), USB1.8 (DP2)
unnamed: R7.2, U1.33 (~HWB~/PE2)
unnamed: R8.1, USB1.4 (CC1)
unnamed: R9.2, USB1.10 (CC2)
RESET: R1.1, SW1.2, U1.13 (~RESET)
ROT_A: C9.1, ENC1.A, R5.2, U1.31 (PC6)
ROT_B: C10.2, ENC1.B, R6.1, U1.32 (PC7)
ROW0: D1.2, D2.2, D3.2, D4.2, D5.2, D6.2, D7.2, D8.2, D9.2, D10.2, D11.2, D12.2, D13.2, D14.2, D15.2, U1.41 (PF0)
ROW1: D16.2, D17.2, D18.2, D19.2, D20.2, D21.2, D22.2, D23.2, D24.2, D25.2, D26.2, D27.2, D28.2, D29.2, D30.2, U1.40 (PF1)
ROW2: D31.2, D32.2, D33.2, D34.2, D35.2, D36.2, D37.2, D38.2, D39.2, D40.2, D41.2, D42.2, D43.2, D44.2, D70.2, U1.39 (PF4)
ROW3: D45.2, D46.2, D47.2, D48.2, D49.2, D50.2, D51.2, D52.2, D53.2, D54.2, D55.2, D56.2, D57.2, D58.2, D59.2, U1.38 (PF5)
ROW4: D60.2, D61.2, D62.2, D63.2, D64.2, D65.2, D66.2, D67.2, D68.2, D69.2, U1.37 (PF6)
R_ENC: D70.1, ENC1.S2
SCL: OL1.2 (SCL), U1.18 (PD0)
SDA: OL1.1 (SDA), U1.19 (PD1)
VCC: C4.1, C5.1, C6.1, C7.1, C8.1, OL1.3 (VCC), R1.2, R4.2, R5.1, R6.2, U1.2 (UVCC), U1.7 (VBUS), U1.14 (VCC), U1.24 (AVCC), U1.34 (VCC), U1.44 (AVCC), USB1.2 (VBUS), USB1.11 (VBUS)
XTAL1: C1.1, U1.17 (XTAL1), X1.1
XTAL2: C2.1, U1.16 (XTAL2), X1.2

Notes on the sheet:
Alt
Ctrl
F17
Down
Right
Shift
F16
LGui
F15
Enter
Tab
F14
BSlash
F13
Equals
Minus
BSpace
Space
RCtrl
RAlt
Left
RShift
Period
Comma
Slash
Quote
Colon
Caps
LBrace
RBrace
Esc
ENC

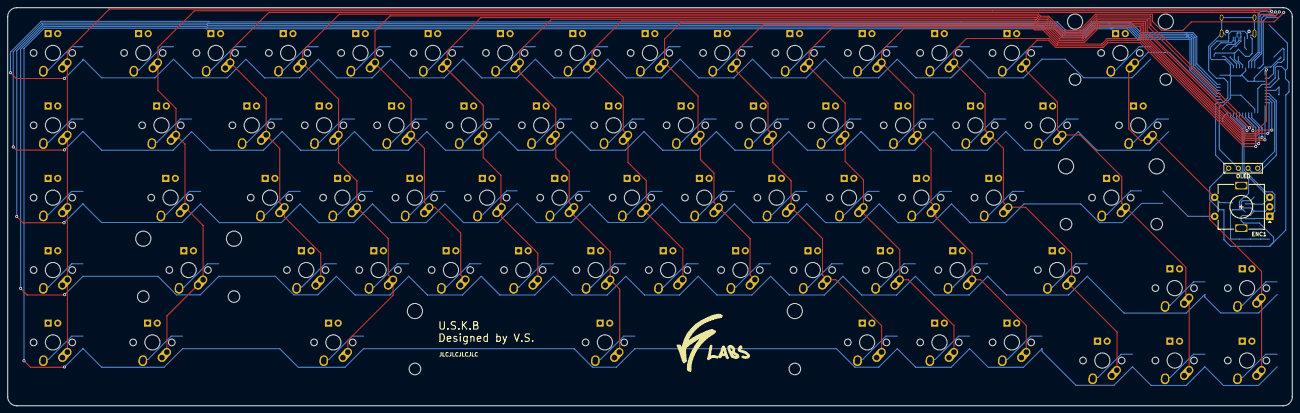
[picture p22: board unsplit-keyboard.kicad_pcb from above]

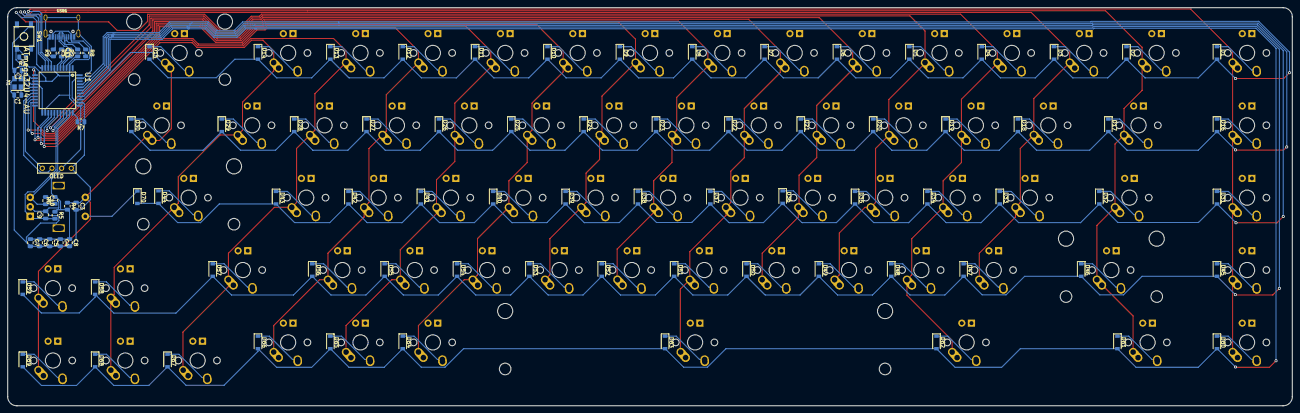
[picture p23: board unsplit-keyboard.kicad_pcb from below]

Board: 2 copper layers, 338.1 x 104.8 mm, 167 parts (94 on the bottom side), 107 nets.

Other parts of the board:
LOGO1: LOGO; logo
LOGO2: LOGO; labs

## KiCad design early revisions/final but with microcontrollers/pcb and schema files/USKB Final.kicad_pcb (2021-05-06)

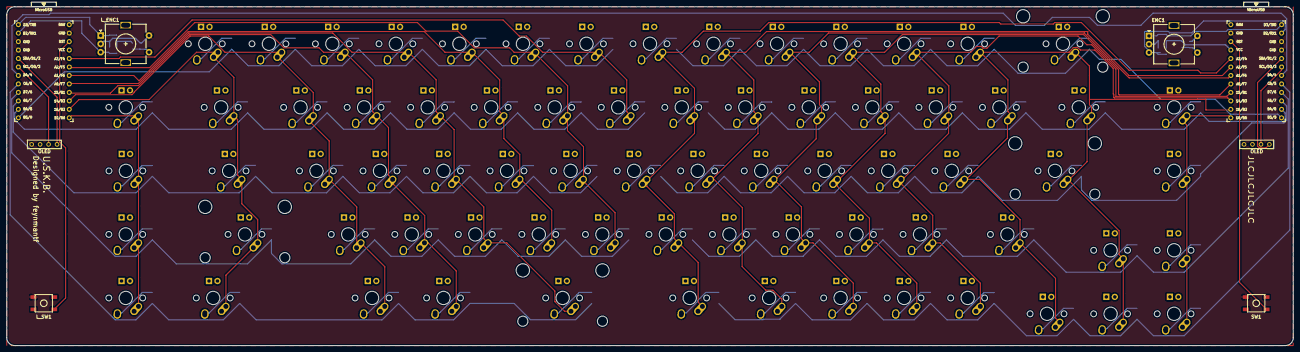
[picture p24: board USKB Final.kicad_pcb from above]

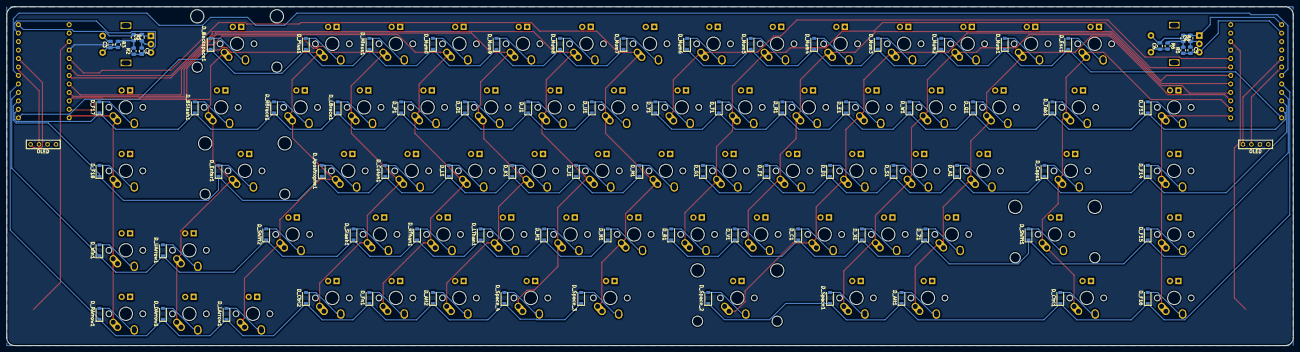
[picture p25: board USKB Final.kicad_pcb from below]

Board: 2 copper layers, 385.8 x 101.6 mm, 166 parts (85 on the bottom side), 114 nets.

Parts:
C1, C2, C3, C4, C5, C6: 0.1u; C_0805_2012Metric
D_A1: SMD_123; D_SOD-123
D_Alt1, D_Alt2: SMD_123; D_SOD-123
D_Apostrophe1: SMD_123; D_SOD-123
D_B1: SMD_123; D_SOD-123
D_BSlash1: SMD_123; D_SOD-123
D_Backspace1: SMD_123; D_SOD-123
D_C1: SMD_123; D_SOD-123
D_Caps1: SMD_123; D_SOD-123
D_Colon1: SMD_123; D_SOD-123
D_Ctrl1, D_Ctrl2: SMD_123; D_SOD-123
D_D1: SMD_123; D_SOD-123
D_DArrow1: SMD_123; D_SOD-123
D_E1: SMD_123; D_SOD-123
D_Enter1: SMD_123; D_SOD-123
D_Esc1: SMD_123; D_SOD-123
D_F1, D_F13, D_F14, D_F15, D_F16, D_F17, D_F18: SMD_123; D_SOD-123
D_Fn1: SMD_123; D_SOD-123
D_G1: SMD_123; D_SOD-123
D_H1: SMD_123; D_SOD-123
D_I1: SMD_123; D_SOD-123
D_J1: SMD_123; D_SOD-123
D_K1: SMD_123; D_SOD-123
D_L1: SMD_123; D_SOD-123
D_LArrow1: SMD_123; D_SOD-123
D_LBrace1: SMD_123; D_SOD-123
D_LThan1: SMD_123; D_SOD-123
D_M1: SMD_123; D_SOD-123
D_Minus1: SMD_123; D_SOD-123
D_N1: SMD_123; D_SOD-123
D_Num0, D_Num1, D_Num2, D_Num3, D_Num4, D_Num5, D_Num6, D_Num7, D_Num8, D_Num9: SMD_123; D_SOD-123
D_O1: SMD_123; D_SOD-123
D_P1: SMD_123; D_SOD-123
D_Plus1: SMD_123; D_SOD-123
D_Q1: SMD_123; D_SOD-123
D_R1: SMD_123; D_SOD-123
D_RArrow1: SMD_123; D_SOD-123
D_RBrace1: SMD_123; D_SOD-123
D_RThan1: SMD_123; D_SOD-123
D_S1: SMD_123; D_SOD-123
D_Shift1, D_Shift2: SMD_123; D_SOD-123
D_Slash1: SMD_123; D_SOD-123
D_Space1: SMD_123; D_SOD-123
D_Space_2, D_Space_3, D_Space_4: SMD_123; D_SOD-123
D_T1: SMD_123; D_SOD-123
D_Tab1: SMD_123; D_SOD-123
D_U1: SMD_123; D_SOD-123
D_UArrow1: SMD_123; D_SOD-123
D_V1: SMD_123; D_SOD-123
D_W1: SMD_123; D_SOD-123
D_Win1: SMD_123; D_SOD-123
D_X1: SMD_123; D_SOD-123
D_Y1: SMD_123; D_SOD-123
D_Z1: SMD_123; D_SOD-123
ENC1: Rotary_Encoder_Switch; RotaryEncoder_Alps_EC11E-Switch_Vertical_H20mm
K_A1: MX-NoLED; MX-1U
K_Alt1: MX-NoLED; MX-1.25U
K_Alt2: MX-NoLED; MX-1U
K_Apostrophe1: MX-NoLED; MX-1U
K_B1: MX-NoLED; MX-1U
K_BSlash1: MX-NoLED; MX-1.5U
K_Backspace1: MX-NoLED; MX-2U
K_C1: MX-NoLED; MX-1U
K_Caps1: MX-NoLED; MX-1.75U
K_Colon1: MX-NoLED; MX-1U
K_Ctrl1: MX-NoLED; MX-1.25U
K_Ctrl2: MX-NoLED; MX-1U
K_D1: MX-NoLED; MX-1U
K_DArrow1: MX-NoLED; MX-1U
K_E1: MX-NoLED; MX-1U
K_Enter1: MX-NoLED; MX-2.25U
K_Esc1: MX-NoLED; MX-1U
K_F1, K_F13, K_F14, K_F15, K_F16, K_F17, K_F18: MX-NoLED; MX-1U
K_Fn1: MX-NoLED; MX-1U
K_G1: MX-NoLED; MX-1U
K_H1: MX-NoLED; MX-1U
K_I1: MX-NoLED; MX-1U
K_J1: MX-NoLED; MX-1U
K_K1: MX-NoLED; MX-1U
K_L1: MX-NoLED; MX-1U
K_LArrow1: MX-NoLED; MX-1U
K_LBrace1: MX-NoLED; MX-1U
K_LThan1: MX-NoLED; MX-1U
K_M1: MX-NoLED; MX-1U
K_Minus1: MX-NoLED; MX-1U
K_N1: MX-NoLED; MX-1U
K_Num0, K_Num1, K_Num2, K_Num3, K_Num4, K_Num5, K_Num6, K_Num7, K_Num8, K_Num9: MX-NoLED; MX-1U
K_O1: MX-NoLED; MX-1U
K_P1: MX-NoLED; MX-1U
K_Plus1: MX-NoLED; MX-1U
K_Q1: MX-NoLED; MX-1U
K_R1: MX-NoLED; MX-1U
K_RArrow1: MX-NoLED; MX-1U
K_RBrace1: MX-NoLED; MX-1U
K_RThan1: MX-NoLED; MX-1U
K_S1: MX-NoLED; MX-1U
K_Shift1: MX-NoLED; MX-2.25U
K_Shift2: MX-NoLED; MX-1.75U
K_Slash1: MX-NoLED; MX-1U
K_Space1: MX-NoLED; MX-1U
K_Space_2: MX-NoLED; MX-2.75U
K_Space_3, K_Space_4: MX-NoLED; MX-1.25U
K_T1: MX-NoLED; MX-1U
K_Tab1: MX-NoLED; MX-1.5U
K_U1: MX-NoLED; MX-1U
K_UArrow1: MX-NoLED; MX-1U
K_V1: MX-NoLED; MX-1U
K_W1: MX-NoLED; MX-1U
K_Win1: MX-NoLED; MX-1U
K_X1: MX-NoLED; MX-1U
K_Y1: MX-NoLED; MX-1U
K_Z1: MX-NoLED; MX-1U
L_ENC1: Rotary_Encoder_Switch; RotaryEncoder_Alps_EC11E-Switch_Vertical_H20mm
L_OL1: OLED
L_SW1: SW_PUSH; SKQG-1155865
L_U1: ProMicro; ProMicro_v3
OL1: OLED
R1, R2, R3, R4, R5, R6: 10k; R_0805_2012Metric
SW1: SW_PUSH; SKQG-1155865
U1: ProMicro; ProMicro_v3

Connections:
COL0: K_H1.1, K_N1.1, K_Num7.1, K_Space_3.1, K_U1.1, U1.20
COL1: K_I1.1, K_J1.1, K_M1.1, K_Num8.1, K_Space_4.1, U1.19
COL2: K_Alt2.1, K_K1.1, K_LThan1.1, K_Num9.1, K_O1.1, U1.18
COL3: K_Fn1.1, K_L1.1, K_Num0.1, K_P1.1, K_RThan1.1, U1.17
COL4: K_Colon1.1, K_Ctrl2.1, K_LBrace1.1, K_Minus1.1, K_Slash1.1, U1.16
COL5: K_Apostrophe1.1, K_LArrow1.1, K_Plus1.1, K_RBrace1.1, K_Shift2.1, U1.15
COL6: K_BSlash1.1, K_Backspace1.1, K_DArrow1.1, K_Enter1.1, K_UArrow1.1, U1.14
COL7: K_F17.1, K_F18.1, K_RArrow1.1, K_Win1.1, U1.13
DATA: L_U1.7, U1.7
GND: C1.1, C2.1, C3.2, C4.1, C5.1, C6.2, ENC1.C, ENC1.S2, L_ENC1.C, L_ENC1.S2, L_OL1.4, L_SW1.2, L_U1.3, L_U1.4, L_U1.23, OL1.4, SW1.2, U1.3, U1.4, U1.23
K_ENC: C3.1, ENC1.S1, R3.2
L_COL0: K_F13.1, K_F14.1, K_F15.1, K_F16.1, L_U1.13
L_COL1: K_Caps1.1, K_Ctrl1.1, K_Esc1.1, K_Shift1.1, K_Tab1.1, L_U1.14
L_COL2: K_A1.1, K_Alt1.1, K_Num1.1, K_Q1.1, K_Z1.1, L_U1.15
L_COL3: K_Num2.1, K_S1.1, K_Space1.1, K_W1.1, K_X1.1, L_U1.16
L_COL4: K_C1.1, K_D1.1, K_E1.1, K_Num3.1, K_Space_2.1, L_U1.17
L_COL5: K_F1.1, K_Num4.1, K_R1.1, K_V1.1, L_U1.18
L_COL6: K_B1.1, K_G1.1, K_Num5.1, K_T1.1, L_U1.19
L_COL7: K_Num6.1, K_Y1.1, L_U1.20
L_K_ENC: C6.1, L_ENC1.S1, R6.2
L_RESET: L_SW1.1, L_U1.22
L_ROT_A: C4.2, L_ENC1.A, L_U1.1, R4.1
L_ROT_B: C5.2, L_ENC1.B, L_U1.2, R5.1
L_ROW0: D_Esc1.1, D_Num1.1, D_Num2.1, D_Num3.1, D_Num4.1, D_Num5.1, D_Num6.1, L_U1.12
L_ROW1: D_E1.1, D_F13.1, D_Q1.1, D_R1.1, D_T1.1, D_Tab1.1, D_W1.1, D_Y1.1, L_U1.11
L_ROW2: D_A1.1, D_Caps1.1, D_D1.1, D_F1.1, D_F14.1, D_G1.1, D_S1.1, L_U1.10
L_ROW3: D_B1.1, D_C1.1, D_F15.1, D_Shift1.1, D_V1.1, D_X1.1, D_Z1.1, L_U1.9
L_ROW4: D_Alt1.1, D_Ctrl1.1, D_F16.1, D_Space1.1, D_Space_2.1, L_U1.8
L_SCL: L_OL1.2, L_U1.6
L_SDA: L_OL1.1, L_U1.5
unnamed: D_A1.2, K_A1.2
unnamed: D_Alt1.2, K_Alt1.2
unnamed: D_Alt2.2, K_Alt2.2
unnamed: D_Apostrophe1.2, K_Apostrophe1.2
unnamed: D_B1.2, K_B1.2
unnamed: D_BSlash1.2, K_BSlash1.2
unnamed: D_Backspace1.2, K_Backspace1.2
unnamed: D_C1.2, K_C1.2
unnamed: D_Caps1.2, K_Caps1.2
unnamed: D_Colon1.2, K_Colon1.2
unnamed: D_Ctrl1.2, K_Ctrl1.2
unnamed: D_Ctrl2.2, K_Ctrl2.2
unnamed: D_D1.2, K_D1.2
unnamed: D_DArrow1.2, K_DArrow1.2
unnamed: D_E1.2, K_E1.2
unnamed: D_Enter1.2, K_Enter1.2
unnamed: D_Esc1.2, K_Esc1.2
unnamed: D_F1.2, K_F1.2
unnamed: D_F13.2, K_F13.2
unnamed: D_F14.2, K_F14.2
unnamed: D_F15.2, K_F15.2
unnamed: D_F16.2, K_F16.2
unnamed: D_F17.2, K_F17.2
unnamed: D_F18.2, K_F18.2
unnamed: D_Fn1.2, K_Fn1.2
unnamed: D_G1.2, K_G1.2
unnamed: D_H1.2, K_H1.2
unnamed: D_I1.2, K_I1.2
unnamed: D_J1.2, K_J1.2
unnamed: D_K1.2, K_K1.2
unnamed: D_L1.2, K_L1.2
unnamed: D_LArrow1.2, K_LArrow1.2
unnamed: D_LBrace1.2, K_LBrace1.2
unnamed: D_LThan1.2, K_LThan1.2
unnamed: D_M1.2, K_M1.2
unnamed: D_Minus1.2, K_Minus1.2
unnamed: D_N1.2, K_N1.2
unnamed: D_Num0.2, K_Num0.2
unnamed: D_Num1.2, K_Num1.2
unnamed: D_Num2.2, K_Num2.2
unnamed: D_Num3.2, K_Num3.2
unnamed: D_Num4.2, K_Num4.2
unnamed: D_Num5.2, K_Num5.2
unnamed: D_Num6.2, K_Num6.2
unnamed: D_Num7.2, K_Num7.2
unnamed: D_Num8.2, K_Num8.2
unnamed: D_Num9.2, K_Num9.2
unnamed: D_O1.2, K_O1.2
unnamed: D_P1.2, K_P1.2
unnamed: D_Plus1.2, K_Plus1.2
unnamed: D_Q1.2, K_Q1.2
unnamed: D_R1.2, K_R1.2
unnamed: D_RArrow1.2, K_RArrow1.2
unnamed: D_RBrace1.2, K_RBrace1.2
unnamed: D_RThan1.2, K_RThan1.2
unnamed: D_S1.2, K_S1.2
unnamed: D_Shift1.2, K_Shift1.2
unnamed: D_Shift2.2, K_Shift2.2
unnamed: D_Slash1.2, K_Slash1.2
unnamed: D_Space1.2, K_Space1.2
unnamed: D_Space_2.2, K_Space_2.2
unnamed: D_Space_3.2, K_Space_3.2
unnamed: D_Space_4.2, K_Space_4.2
unnamed: D_T1.2, K_T1.2
unnamed: D_Tab1.2, K_Tab1.2
unnamed: D_U1.2, K_U1.2
unnamed: D_UArrow1.2, K_UArrow1.2
unnamed: D_V1.2, K_V1.2
unnamed: D_W1.2, K_W1.2
unnamed: D_Win1.2, K_Win1.2
unnamed: D_X1.2, K_X1.2
unnamed: D_Y1.2, K_Y1.2
unnamed: D_Z1.2, K_Z1.2
RESET: SW1.1, U1.22
ROT_A: C1.2, ENC1.A, R1.1, U1.1
ROT_B: C2.2, ENC1.B, R2.1, U1.2
ROW0: D_Backspace1.1, D_Minus1.1, D_Num0.1, D_Num7.1, D_Num8.1, D_Num9.1, D_Plus1.1, U1.12
ROW1: D_BSlash1.1, D_F17.1, D_I1.1, D_LBrace1.1, D_O1.1, D_P1.1, D_RBrace1.1, D_U1.1, U1.11
ROW2: D_Apostrophe1.1, D_Colon1.1, D_Enter1.1, D_F18.1, D_H1.1, D_J1.1, D_K1.1, D_L1.1, U1.10
ROW3: D_LThan1.1, D_M1.1, D_N1.1, D_RThan1.1, D_Shift2.1, D_Slash1.1, D_UArrow1.1, D_Win1.1, U1.9
ROW4: D_Alt2.1, D_Ctrl2.1, D_DArrow1.1, D_Fn1.1, D_LArrow1.1, D_RArrow1.1, D_Space_3.1, D_Space_4.1, U1.8
SCL: OL1.2, U1.6
SDA: OL1.1, U1.5
VCC: L_OL1.3, L_U1.21, OL1.3, R1.2, R2.2, R3.1, R4.2, R5.2, R6.1, U1.21

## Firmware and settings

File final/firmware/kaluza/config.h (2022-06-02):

/* Copyright 2021 feynmantf
 *
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
 * You should have received a copy of the GNU General Public License
 * along with this program.  If not, see <http://www.gnu.org/licenses/>.
 */

#pragma once

#include "config_common.h"

/* USB Device descriptor parameter */
#define VENDOR_ID 0xFEED
#define PRODUCT_ID 0x0000
#define DEVICE_VER 0x0001
#define MANUFACTURER FeynLabs
#define PRODUCT Kaluza

/* key matrix size */
#define MATRIX_ROWS 5
#define MATRIX_COLS 15

/*
 * Keyboard Matrix Assignments
 *
 * Change this to how you wired your keyboard
 * COLS: AVR pins used for columns, left to right
 * ROWS: AVR pins used for rows, top to bottom
 * DIODE_DIRECTION: COL2ROW = COL = Anode (+), ROW = Cathode (-, marked on diode)
 *                  ROW2COL = ROW = Anode (+), COL = Cathode (-, marked on diode)
 *
 */
#define MATRIX_ROW_PINS \
    { B7, D5, C7, F1, F0 }
#define MATRIX_COL_PINS \
    { D4, C6, D7, E6, B4, B5, B0, F4, F5, F6, F7, B1, B3, B2, B6 }

#define DIODE_DIRECTION COL2ROW

#define ENCODERS_PAD_A \
    { D3 }
#define ENCODERS_PAD_B \
    { D2 }
#define ENCODER_RESOLUTION 4

#define FORCE_NKRO

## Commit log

2021-03-08 initialize project
    [custom-mech.sch]
2021-03-09 basic schematic (no footprints yet)
    [custom-mech.sch]
2021-03-09 added footprints
    [custom-mech.sch]
2021-03-09 saved lol
    [custom-mech.sch]
2021-03-09 finished pcb
    [custom-mech atmega.kicad_pcb, custom-mech.sch]
2021-03-09 moved test board to new folder
    [custom-mech atmega.kicad_pcb, custom-mech.kicad_pcb, custom-mech.sch]
2021-03-09 started new board / added libraries
    [Marvelous65 Split.kicad_pcb, Marvelous65 Split.kicad_sch]
2021-03-10 added libs for new schema
    [pro micro version.kicad_pcb, pro micro version.sch]
2021-03-10 started a little on pro micro version
    [Marvelous65 Split.kicad_sch, Marvelous65 Split.sch, custom-mech - Copy.kicad_pcb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]
2021-03-10 small updates
    [custom-mech atmega.kicad_pcb, custom-mech.sch]
2021-03-11 left side done plus cleanup of folders and stuff
    [custom-mech - Copy.kicad_pcb, custom-mech atmega.kicad_pcb, custom-mech.kicad_pcb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]
2021-03-11 finished sechma
    [pro micro version.sch]
2021-03-11 trying to fix library errors in kicad
    [Marvelous65 Split.kicad_pcb, Marvelous65 Split.sch, pro micro version.sch]
2021-03-11 new library and assigned footprints to schematic
    [pro micro version.sch]
2021-03-11 laid out keys on pcb still need to do diodes and stuff
    [pro micro version.sch]
2021-03-12 finished first routing
    [pro micro version new traces.kicad_pcb, pro micro version.sch]
2021-03-12 autosave ig
    [pro micro version new traces.kicad_pcb]
2021-03-12 finalized traces
    [pro micro version new traces.sch]
2021-03-12 finalized pcb design
    [USKB Final.kicad_pcb, USKB Final.sch, pro micro version new traces.kicad_pcb]
2021-03-12 organized and exported files
    [USKB Final-B_Cu.gbr, USKB Final-B_Mask.gbr, USKB Final-B_Paste.gbr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]
2021-03-12 made gerbers
    [USKB Final-NPTH.drl, USKB Final-PTH.drl]
2021-03-12 generated bom and cpl
    [USKB Final.kicad_pcb, USKB Final_Jlcpcb_BOM.csv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]
2021-03-14 updated footprints and cpl to match cap set
    [USKB Final-B_Cu.gbr, USKB Final-B_Mask.gbr, USKB Final-B_Paste.gbr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]
2021-03-15 made cad for plate, made gerbers and a bunch of other stuff
    [USKB Final-B_Cu.gbr, USKB Final-B_Mask.gbr, USKB Final-B_Paste.gbr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]
2021-04-13 i realized a fatal error
    [USKB Final but wrong and needs to be redone sadge-B_Cu.gbr, USKB Final but wrong and needs to be redone sadge-B_Mask.gbr, USKB Final but wrong and needs to be 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]
2021-04-13 made necessary changes i think (kinda tempted to rewire the whole thing but drc runs perfectly soooooo)
    [USKB Final-B_Cu.gbr, USKB Final-B_Mask.gbr, USKB Final-B_Paste.gbr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]
2021-04-13 made plate files and maybe rest of case files too but thatll be expensive soooo
    [bottom layer.dxf, closed layer.dxf, open layer.dxf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]
2021-04-14 adjusted plate/case files to be aligned with pcb hopefully
    [USKB Final-F_SilkS.dxf, USKB Final.kicad_pcb, USKB Final.sch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]
2021-04-15 did a bunch of stuff, but the main thing is make all of the case files almost perfect
    [USKB Final but wrong and needs to be redone sadge-B_Cu.gbr, USKB Final but wrong and needs to be redone sadge-B_Mask.gbr, USKB Final but wrong and needs to be 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]
2021-04-15 finalized plate and case files fixed space bars and created a hole for reset switch
    [bottom.dwg, closed.dwg, everything on top of one another theres smt wrong with space and i need to make a cutout on the switch layer for the resets.dwg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]
2021-04-15 added pcb svgs
    [USKB Final-F_SilkS.dxf, bottom.dwg, closed.dwg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]
2021-04-16 moved some stuff around lmao
    [USKB Final-B_Cu.gbr, USKB Final-B_Mask.gbr, USKB Final-B_Paste.gbr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]
2021-05-04 changed bottom row to be more accessible
    [USKB Final-B_Adhes.gbr, USKB Final-B_CrtYd.gbr, USKB Final-B_Cu.gbr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]
2021-05-04 fixed reset switch cutout size
    [switch.dwg]
2021-05-06 fixed duplicate and overlapping cuts
    [USKB Final-F_SilkS.dwg, USKB Final-F_SilkS.dxf, bottom.dwg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]
2021-05-06 changed smt lol
    [USKB Final-B_Adhes.gbr, USKB Final-B_CrtYd.gbr, USKB Final-B_Cu.gbr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]
2021-07-08 new pcb beginnings
    [USKB Final-B_Adhes.gbr, USKB Final-B_CrtYd.gbr, USKB Final-B_Cu.gbr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]
2021-07-10 fixed almost everything on the entire keyboard
    only need to buy new oled panel and test it, then layout new pcb, print them, layout new plate file, print it, and make a new case
    [unsplit-keyboard.sch]
2021-07-10 updated readme to make more sense with changes made to rest of board
2021-07-10 change resistor amounts
2021-07-10 firmware files uploaded
    [unsplit-keyboard.sch]
2021-07-14 everything but simulation done
    [unsplit-keyboard but the wires suck and are incomplete.kicad_pcb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]
2021-07-14 fixed 3d part library and bom
    [unsplit-keyboard.csv]
2021-07-14 added images
    [unsplit-keyboard.csv]
2021-07-16 updated gerbers and all that
    [unsplit-keyboard-B_Cu.gbr, unsplit-keyboard-B_Mask.gbr, unsplit-keyboard-B_Paste.gbr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]
2021-07-18 finalized rev 2 and ordered on jlc
    [34e1b9ccf366a24b1eb1e18adc3a0b180d021cdd_switch.dxf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]
2021-07-19 fixed footprint for diodes and finalized plate file
    [34e1b9ccf366a24b1eb1e18adc3a0b180d021cdd_switch.dxf, plate.dxf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]
2021-08-29 renaming to kaluza p1
    [kaluza.kicad_pcb, kaluza.sch, plate.dxf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]
2021-11-14 new layout
    [kaluza.sch]
2021-11-14 laid out basically everything but diodes on pcb
    [kaluza.kicad_pcb, kaluza.sch]
2022-05-20 idk what changed
    [kaluza.kicad_pcb]
2022-09-21 small update + looking at chip info
    [kaluza.kicad_sch]
2022-09-29 created schema image for final and added photos of the handwired board

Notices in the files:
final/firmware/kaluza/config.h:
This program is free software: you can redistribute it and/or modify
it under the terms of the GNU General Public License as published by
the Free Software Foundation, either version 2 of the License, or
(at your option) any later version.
